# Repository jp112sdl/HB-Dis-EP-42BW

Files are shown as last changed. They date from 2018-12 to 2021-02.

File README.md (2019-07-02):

# HB-Dis-EP-42BW (jetzt auch mit Color-Display Unterstützung)

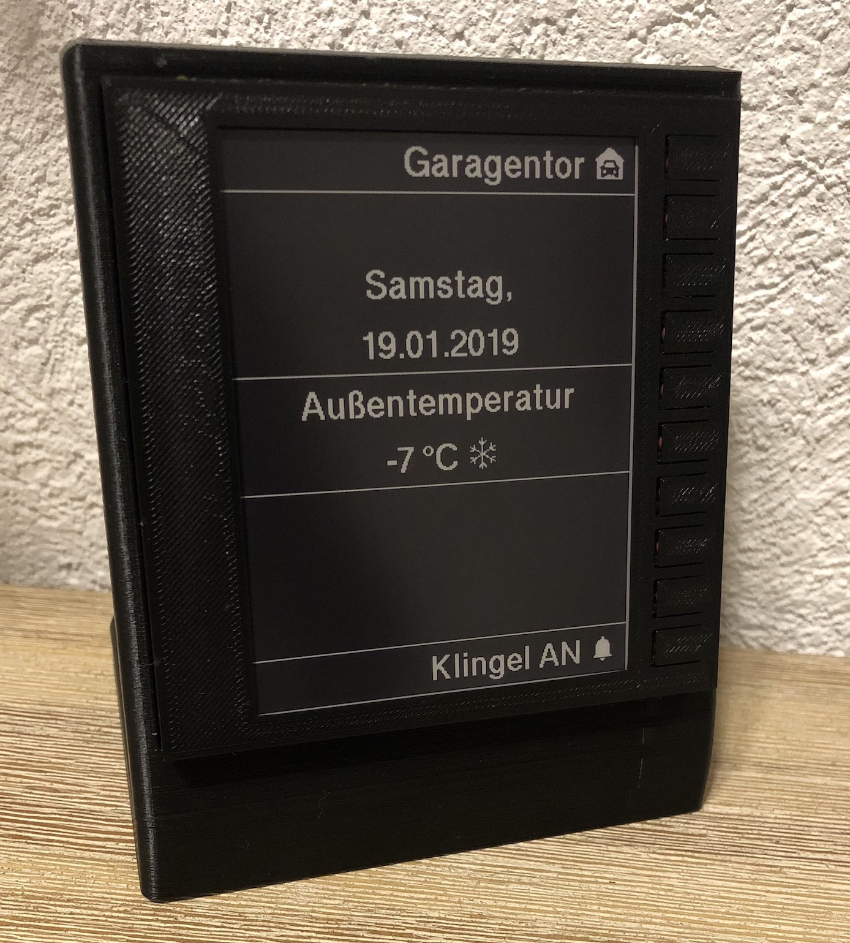
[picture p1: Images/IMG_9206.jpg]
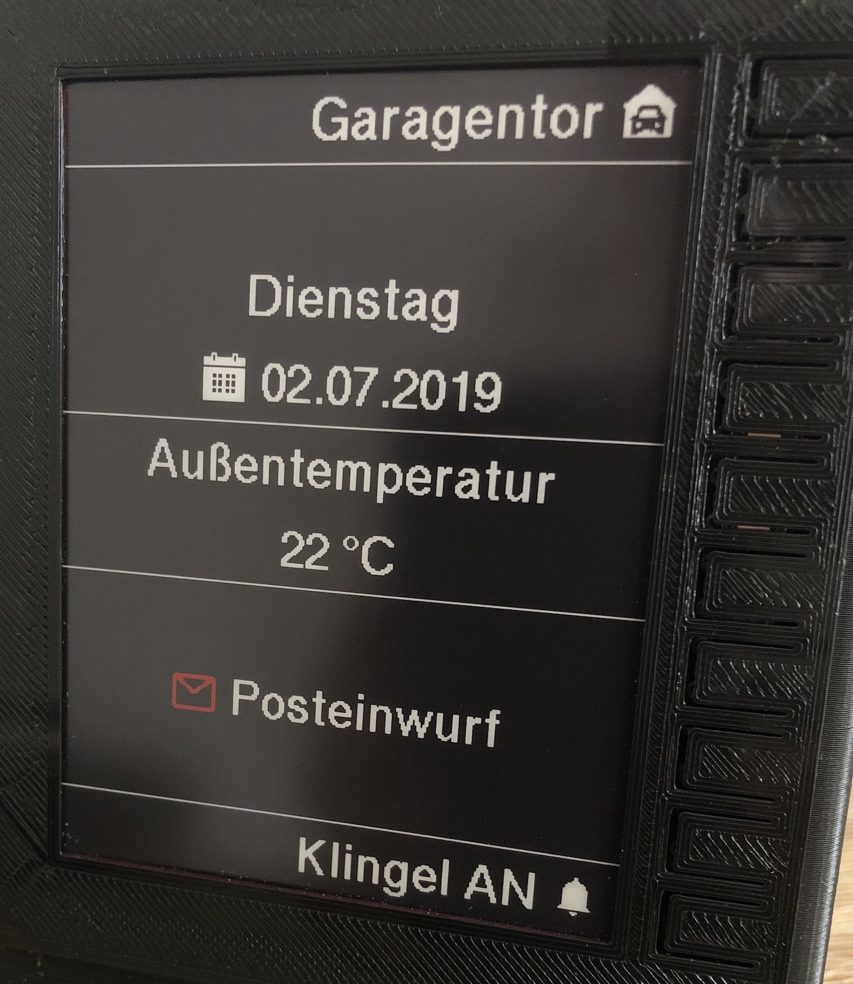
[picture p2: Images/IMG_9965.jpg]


## Infos
Thread im Homematic-Forum: https://homematic-forum.de/forum/viewtopic.php?f=76&t=48153

## Parts
- ATMega **1284P** (für den [Prototypen](https://github.com/jp112sdl/HB-Dis-EP-42BW/blob/master/Images/IMG_9180.jpg) habe ich die [HM-ES-PWMSw1-Pl_GosundSP1-Platine](https://raw.githubusercontent.com/stan23/HM-ES-PMSw1-Pl_GosundSP1/master/Bilder/Platine_V2_bestückt.jpg) missbraucht ^^)
- 11 Taster (10 Tasterkanäle + 1 Anlerntaster)
- 2 Widerstände 330 Ohm
- 2 LEDs oder 1 Dual-Color-LED
- 4.2" ePaper Display
  - [mit SPI Interface](https://www.exp-tech.de/new/8289/400x300-4.2-e-ink-display-module), passt dann jedoch nicht in die [Frontabdeckung](Images/ePaper-Front.stl) - da ist dann eigene Kreativität gefragt
  - [mit RAW Interface](https://www.exp-tech.de/displays/e-paper-e-ink/8885/waveshare-4.2-e-ink-raw-display-400x300), setzt jedoch noch ein SPI-Treiberboard voraus
    - [Universal e-Paper Raw Panel Driver HAT](https://www.exp-tech.de/displays/e-paper-e-ink/8525/universal-e-paper-raw-panel-driver-hat) oder
    - [CrystalFontz ePaper Adapter Board](https://www.crystalfontz.com/product/cfa10084-epaper-adapter-board)
- 2x 2fach AAA Batteriehalter (werden parallel betrieben; passte am besten ins [Gehäuse](https://github.com/jp112sdl/HB-Dis-EP-42BW/blob/master/Images/IMG_9181.jpg))    

## Arduino
- [MCUDude/MightyCore Board](https://github.com/MCUdude/MightyCore)-Unterstützung für den 1284P
  - Pinout: Standard
  - Clock: 8MHz external
  - BOD: Disabled
  - Compiler LTO: Disabled
  - Variant: 1284P
- Bibliotheken:  
  - [AskSinPP](https://github.com/pa-pa/AskSinPP) (master-Branch verwenden!)
  - [Low-Power](https://github.com/rocketscream/Low-Power)
  - [EnableInterrupt](https://github.com/GreyGnome/EnableInterrupt)
  - [GxEPD](https://github.com/ZinggJM/GxEPD) 
    - :arrow_right: um die Display-Aktualisierungsdauer zu verringern, lohnt es sich, in der `GxGDEW042T2.h` den Wert für [`GxGDEW042T2_PAGES`](https://github.com/ZinggJM/GxEPD/blob/master/src/GxGDEW042T2/GxGDEW042T2.h#L25) auf `3` zu reduzieren
  - [Adafruit-GFX](https://github.com/adafruit/Adafruit-GFX-Library)
  - [U8g2_for_Adafruit_GFX](https://github.com/olikraus/U8g2_for_Adafruit_GFX)

## Gehäuse
### Stand
https://www.thingiverse.com/thing:3331473

### Front
[Front](Images/ePaper-Front.stl)

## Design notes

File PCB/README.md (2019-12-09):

# HB-Dis-EP-42BW Platine     

# Work in Progress - in Bearbeitung...

# Hardware

### Bauteile

#### Reichelt

[Bestellliste](https://www.reichelt.de/my/1564026) (ohne die optionalen Bauteile)

Bauteil                  | Bestellnummer    | Anzahl | Kommentar
------------------------ | ---------------- | ------ | ---------
C1                       | X5R-G0603 10/6   |   1    | -
C2 .. C5, C7             | X7R-G0603 100N   |   5    | -
C6, C8                   | X7R-G0603 1,0/16 |   2    | -
D1                       | KBT L-115WEGW    |   1    | -
R1, R5                   | RND 0603 1 10K   |   2    | -
R2 .. R3                 | RND 0603 1 330   |   2    | -
R4                       | RND 0603 1 1,0M  |   1    | -
R6                       | RND 0603 1 4,7k  |   1    | optional: für Batteriespannungsmessung unter Last
R7                       | RND 155HP05 CI   |   1    | optional: für Batteriespannungsmessung unter Last
R8                       | RND 155HP05 AF   |   1    | optional: für Batteriespannungsmessung unter Last
Q1                       | IRLML 6344       |   1    | optional: für Batteriespannungsmessung unter Last
SW0                      | TASTER 3301      |   1    | optional: Konfigtaster *Achtung, diese Bauhöhe ist für die Montage kopfüber!*
SW1 .. SW10              | JTP-1130         |  10    | *Achtung, evtl. andere Bauhöhe!*
U1                       | ATMEGA 1284P-AU  |   1    | -
Y1                       | CSTCE 8,00       |   1    | -
Verbinder zum CC1101     | MPE 150-1-010    |   1    | -
Verbinder zum ePaper     | MPE 087-1-010    |   1    | -
Verbinder zur Batterie   | -                |   -    | optional, kann auch angelötet werden
Batteriefach             | HALTER 2XUM4-NLF |   -    | optional, für 2x AAA
Batteriefach             | HALTER 2XAAZ     |   -    | optional, für 2x AA

#### Farnell

Bauteil                  | Bestellnummer    | Anzahl | Kommentar
------------------------ | ---------------- | ------ | ---------
U3                       | [MCP111T-270E/TT](https://de.farnell.com/microchip/mcp111t-270e-tt/ic-supervisor-2-63v-low-sot-23b/dp/1851877)  |   1    | optional, Unterspannungserkennung

#### Sonstiges

Bauteil | Bezeichnung                  | Anzahl | Kommentar
------- | ---------------------------- | ------ | ---------
U2      | CC1101 Funkmodul 868 MHz     |   1    | z.B. [eBay](https://www.ebay.de/itm/272455136087)
Display | 4,2" ePaper mit SPI-Anschluss|   1    | z.B. [EXP-R63-045](https://www.exp-tech.de/new/8289/400x300-4.2-e-ink-display-module)

~8,3 cm Draht als Antenne

### Programmieradapter
- 1x ISP (z.B. [diesen hier](https://www.diamex.de/dxshop/USB-ISP-Programmer-fuer-Atmel-AVR-Rev2))

# Software

### Fuses und Lockbits

Fuse     | Wert | Kommentar
-------- | ---- | ---------
Extended | 0xFF |
High     | 0xD4 |
Low      | 0xFF |
Lockbits | 0xEF | optional

`C:\Program Files (x86)\Arduino\hardware\tools\avr\bin> .\avrdude -C ..\etc\avrdude.conf -p m1284p -P com7 -c stk500 -U lfuse:w:0xFF:m -U hfuse:w:0xD4:m -U efuse:w:0xFF:m`

### Firmware

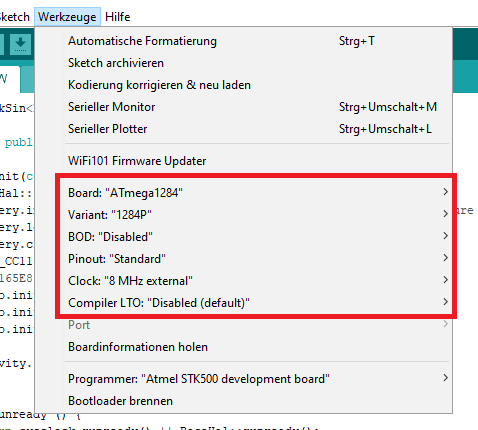
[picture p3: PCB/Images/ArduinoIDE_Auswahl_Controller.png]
Einstellungen IDE


# Bauanleitung

Zuerst den ATmega auflöten, die Markierung (kleiner Punkt) muss zur Beschriftung U1 zeigen.
Danach den Resonator, die Kondensatoren und Widerstände auflöten.

Mit einem Multimeter messen ob kein Kurzschluss zwischen VCC und GND besteht (mehrere 10 K Widerstand sind okay).

Den ISP Programmieradapter an den 6-poligen Anschluss auf der **Rückseite** anschließen.
Nun kann entweder der Sketch direkt geflasht werden ("Hochladen mit Programmer"), oder zuerst der [Bootloader](https://github.com/TomMajor/SmartHome/tree/master/Info/Bootloader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) und dann der eigentliche Sketch über den FTDI-Anschluss.

Pin am ISP-Kabel | Bedeutung
---------------- | ----------
1                | MISO
2                | VCC
3                | SCK
4                | MOSI
5                | Reset
6                | GND

Anschließend können das Funkmodul, die Taster und die LED eingelötet werden.

An den Antennenanschluss muss noch das 8,3 cm Drahtstück angelötet werden.

Mit einem FTDI USB-seriell-Adapter und einem Terminalprogramm kann man die Ausgabe beobachten. Es sollten schon *Ignore...*-Meldungen empfangen und angezeigt werden.

# ToDo

#### Abstände ePaper zu Platine
#### Höhe der Taster
#### Konfigtaster
Orientierung wie die anderen 10 Taster, oder über Kopf.
#### Ausrichtung LED
#### Abstandsbolzen
#### Befestigung im Gehäuse
#### Batterien 2x AA statt 2x 2x AAA

# Bilder



Dieses Werk ist lizenziert unter einer [Creative Commons Namensnennung - Nicht-kommerziell - Weitergabe unter gleichen Bedingungen 3.0 International Lizenz](http://creativecommons.org/licenses/by-nc-sa/3.0/).

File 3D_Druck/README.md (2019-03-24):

# HB-Dis-EP-42BW-3D-Modell

front.stl für diesen Display Version:
https://www.waveshare.com/4.2inch-e-Paper.htm

front-spi_pcb.stl für diesen Display Version:
https://www.waveshare.com/4.2inch-e-paper-module.htm

Standard Dicke 0,4 bei der Version 06 ist die Front 0,6mm Dick

Die Basis ist passend für beide Versionen und hat ein extra großes Batteriefach.

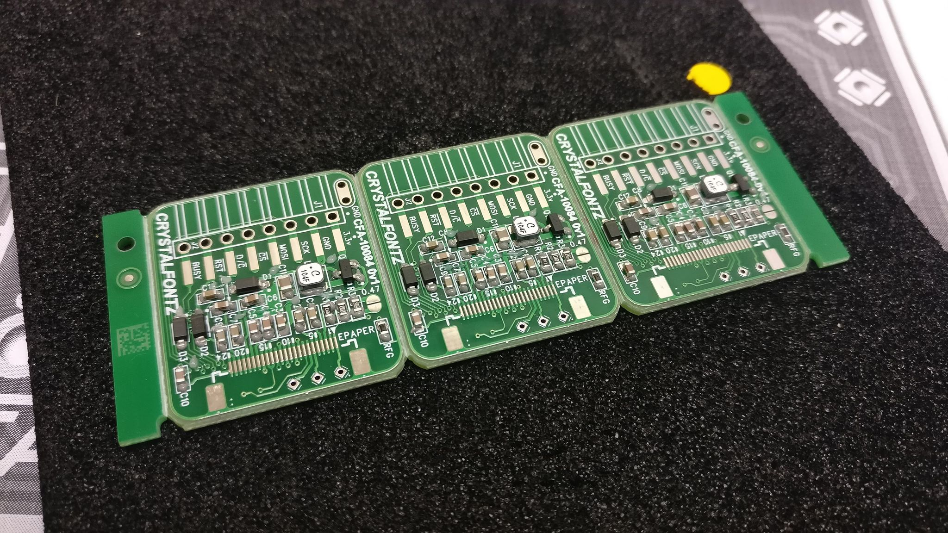
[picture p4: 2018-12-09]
Images/CF_Platine1.jpg

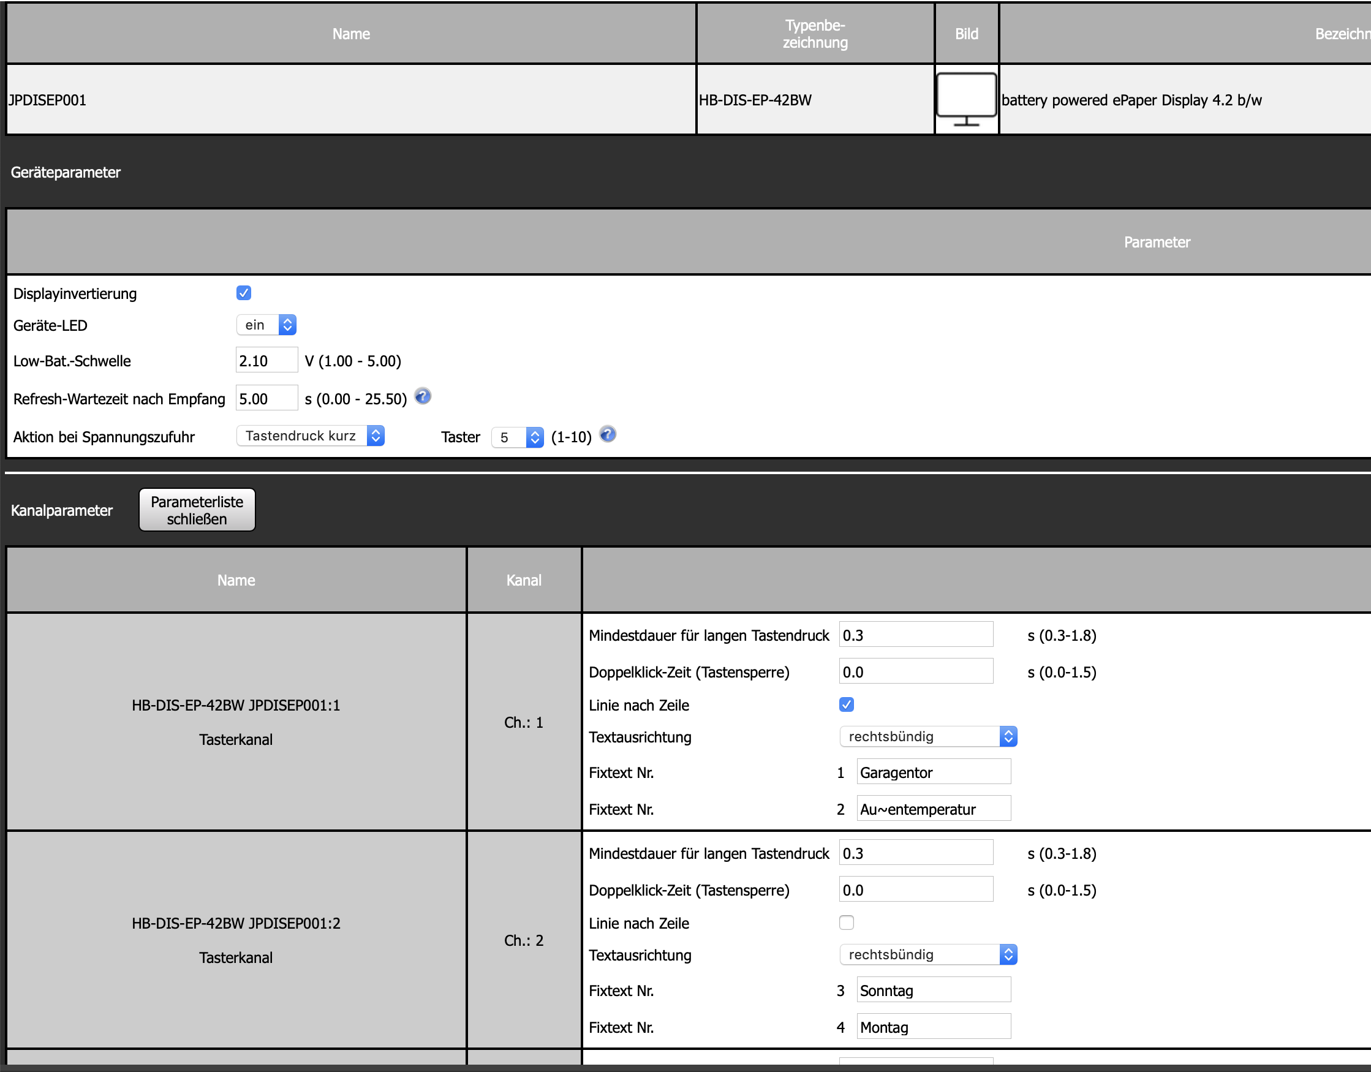
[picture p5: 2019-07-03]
Images/CCU_Einstellungen.png

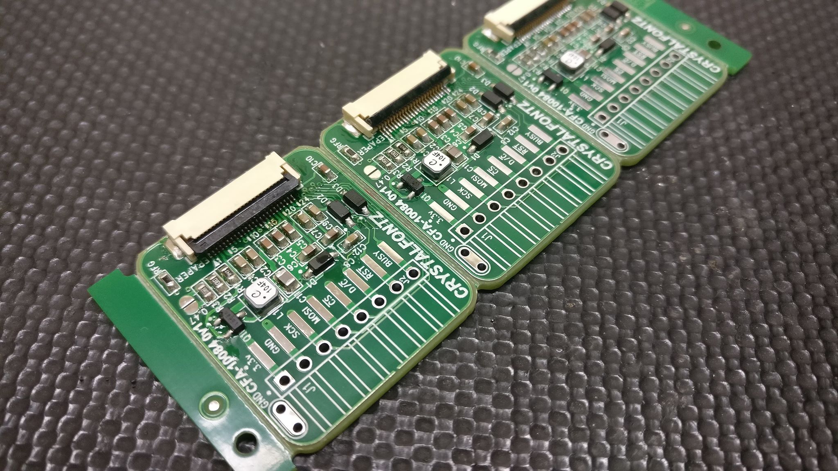
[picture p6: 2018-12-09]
Images/CF_Platine2.jpg

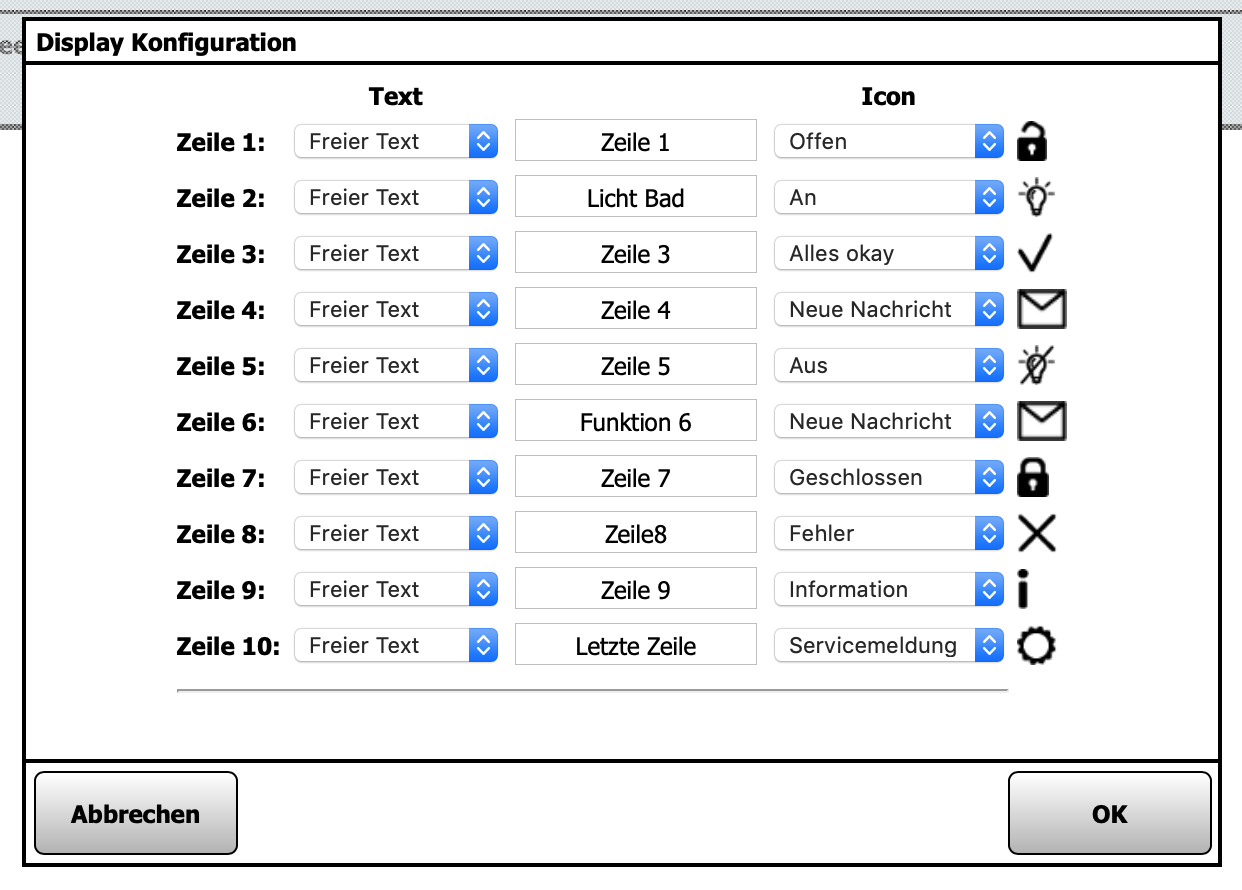
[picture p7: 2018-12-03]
Images/CCU_Programm_CH11.png

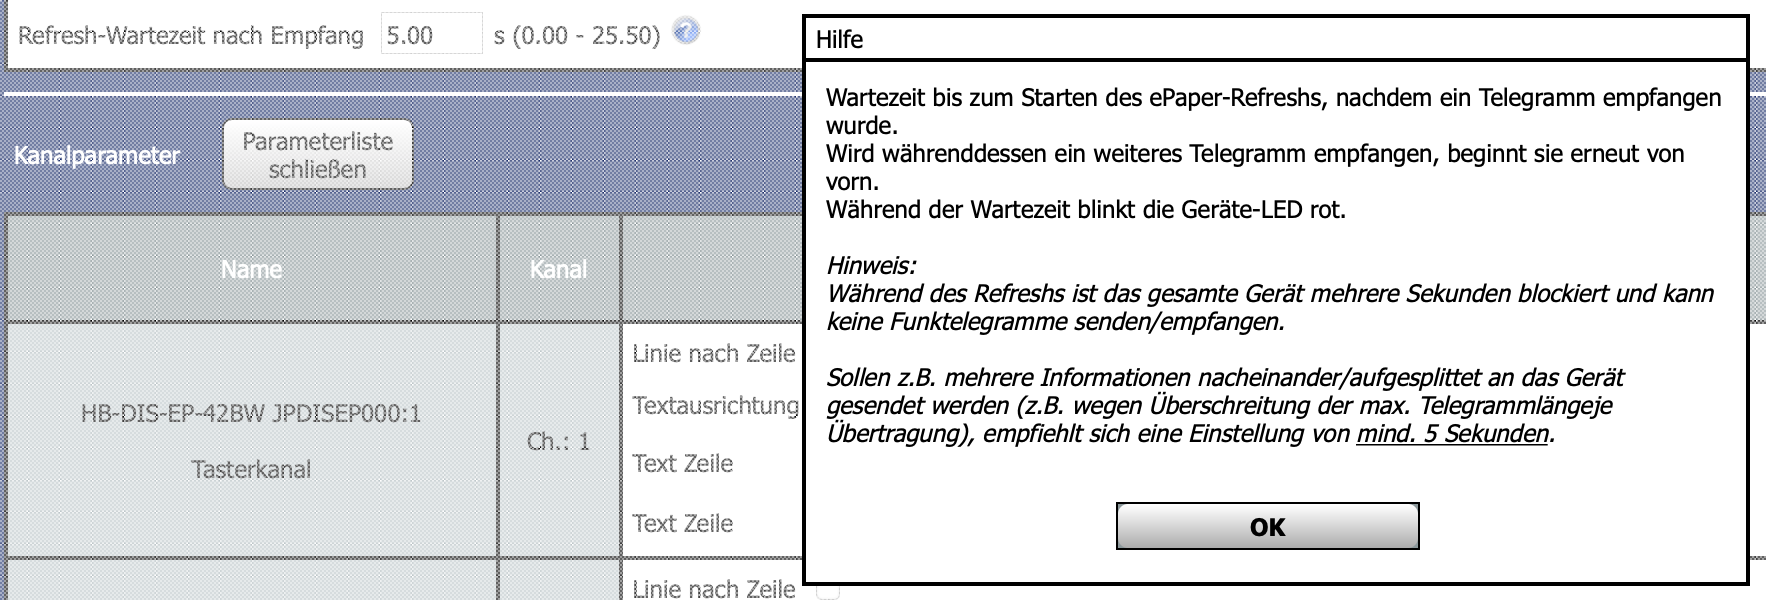
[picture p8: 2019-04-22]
Images/CCU_Einstellungen_Hilfe.png

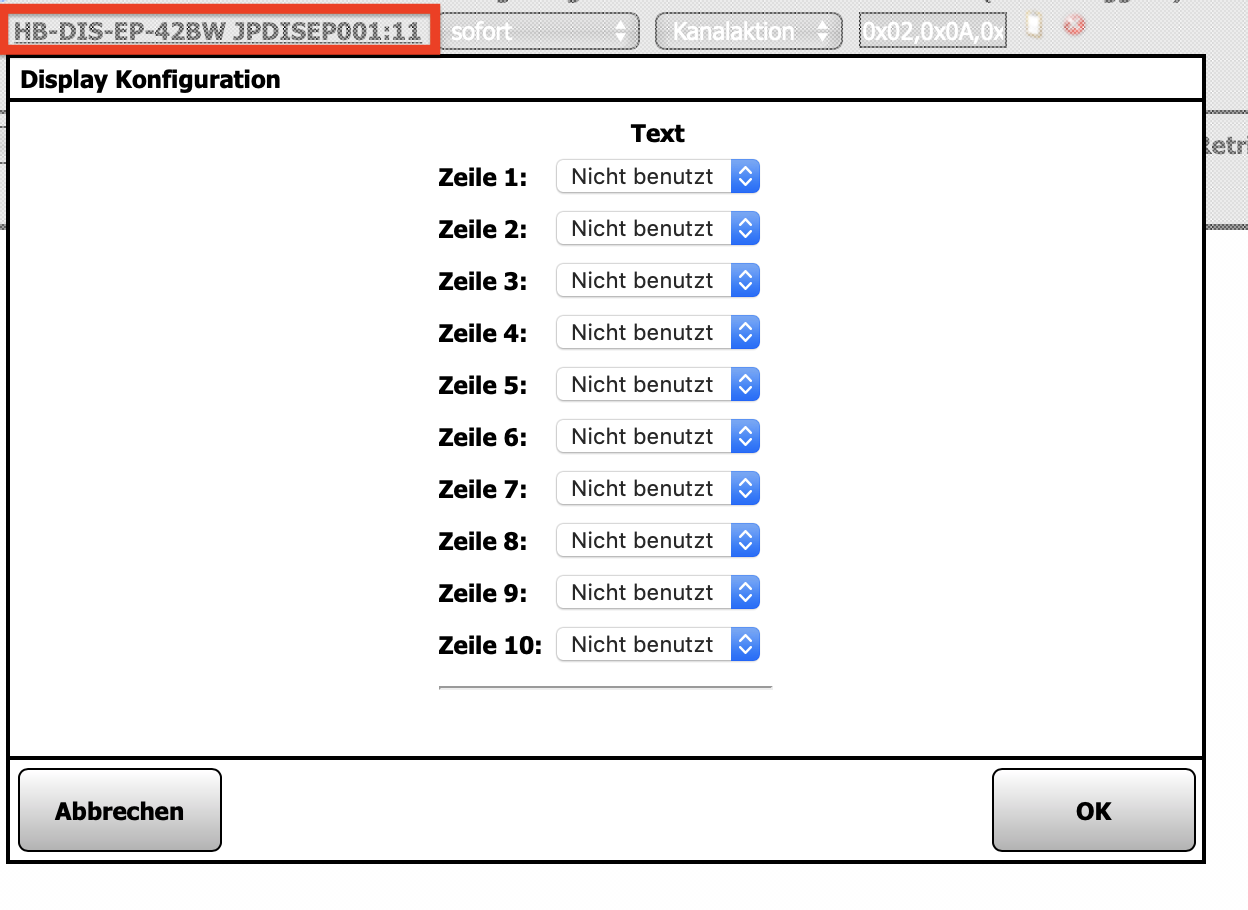
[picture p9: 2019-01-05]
Images/CCU_Programm.png

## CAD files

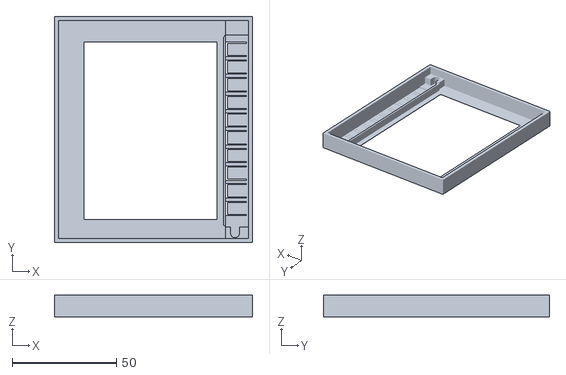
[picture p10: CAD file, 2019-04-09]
3D_Druck/front-spi.stl
95.0 x 108.6 x 10.4

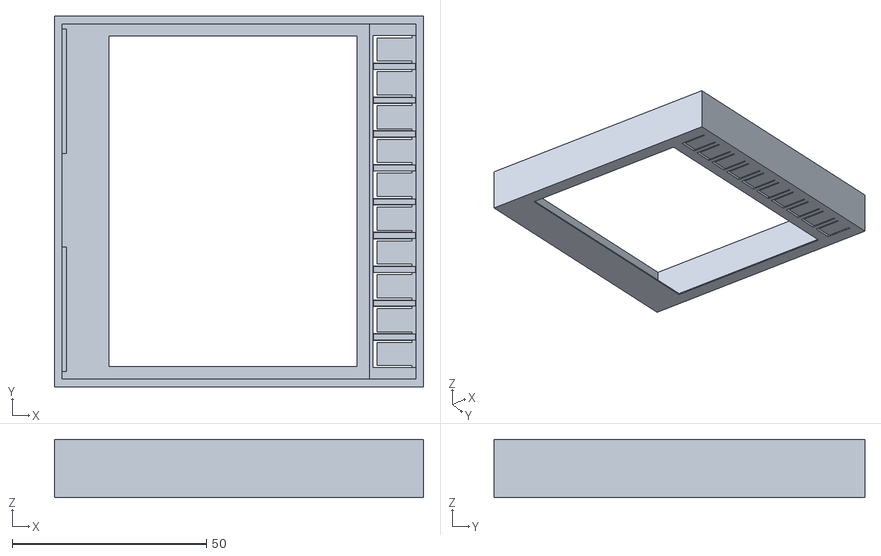
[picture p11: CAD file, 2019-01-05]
Images/ePaper-Front.stl
95.0 x 95.4 x 15.0

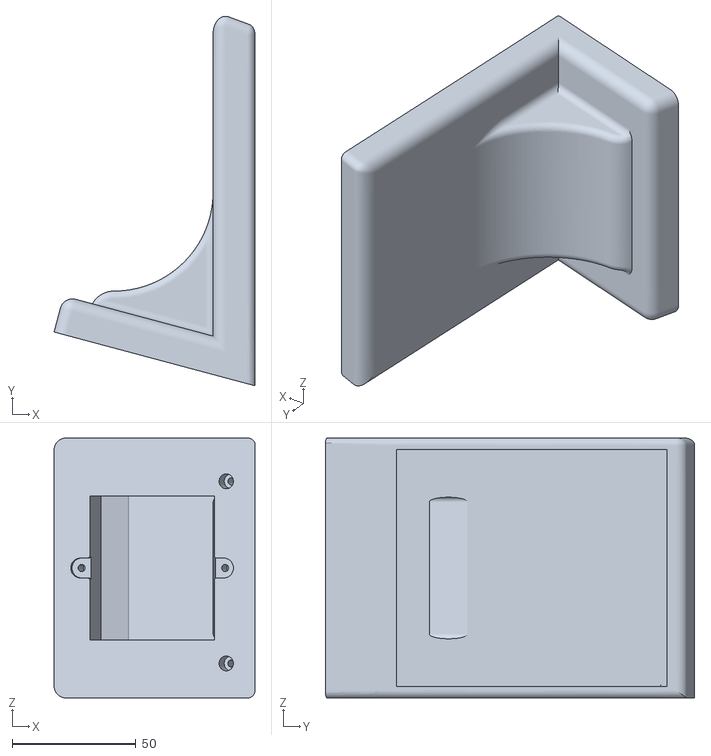
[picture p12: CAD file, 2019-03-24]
3D_Druck/basis.stl
81.2 x 149.2 x 105.0

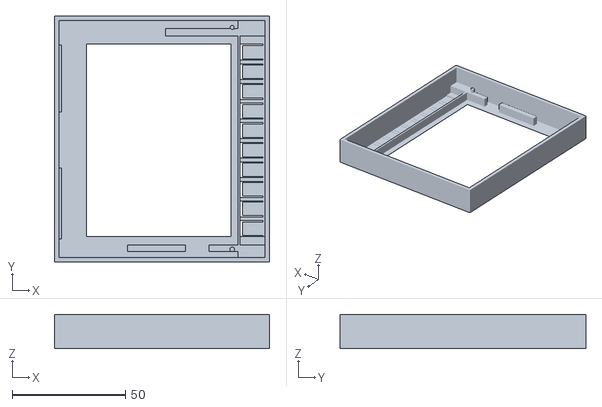
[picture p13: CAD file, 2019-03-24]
3D_Druck/front.stl
95.0 x 108.6 x 15.0

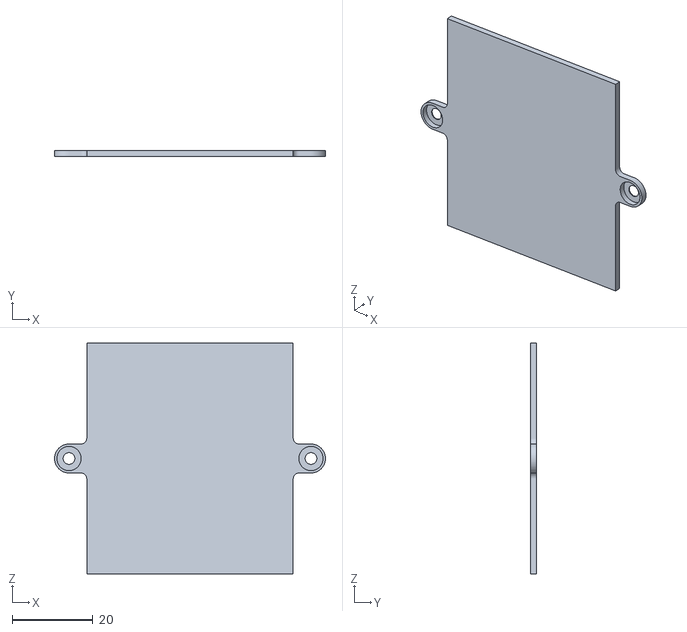
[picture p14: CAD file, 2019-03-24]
3D_Druck/Basis_Batterie_Deckel.stl
67.2 x 1.60 x 57.2

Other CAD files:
3D_Druck/front06.stl

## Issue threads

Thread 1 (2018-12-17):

add BI protection

stan23, 2018-12-17:
A protection against [Babbling Idiot](https://github.com/TomMajor/AskSinPP_Examples/tree/master/Info/Babbling%20Idiot%20Protection) shall be added.
If it is not populated, there shall be a way to bypass it.

stan23, 2019-01-13:
Two options to circumvent BIs are added to the PCB in https://github.com/jp112sdl/HB-Dis-EP-42BW/commit/53e460dccab44cdeac5f58302a134860578abbe9
- battery measurement under load
- external BOD (MCP111)

Both are optional to populate.

Closed 2019-01-13.

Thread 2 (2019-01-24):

Dreifarbiges Waveshare E-Paper Display

Alveran81, 2019-01-24:
Hallo,
ist es möglich auch das dreifarbige E-Paper Display einzubinden? Habe versehentlich das falsche bestellt. Es würde auch reichen wenn rot erstmal nicht verwendet wird.
Genau gesagt dieses:
https://www.waveshare.com/wiki/4.2inch_e-Paper_Module_(B)
https://eckstein-shop.de/Waveshare-42-inch-400x300-E-Ink-E-Paper-Display-Module-Three-color-Arduino

Welche Library muss dafür geladen werden? Hab schon ewig im Netz dazu gesucht, konnte aber nichts sinnvolles finden.

jp112sdl, 2019-01-24:
Moin,

ja das geht. Ich hab bei mir auch das 3farbige und nutze nur b/w. 😄

Libs brauchst du alle, die hier unten aufgeführt sind:
https://github.com/jp112sdl/HB-Dis-EP-42BW#arduino

Closed 2019-02-04.

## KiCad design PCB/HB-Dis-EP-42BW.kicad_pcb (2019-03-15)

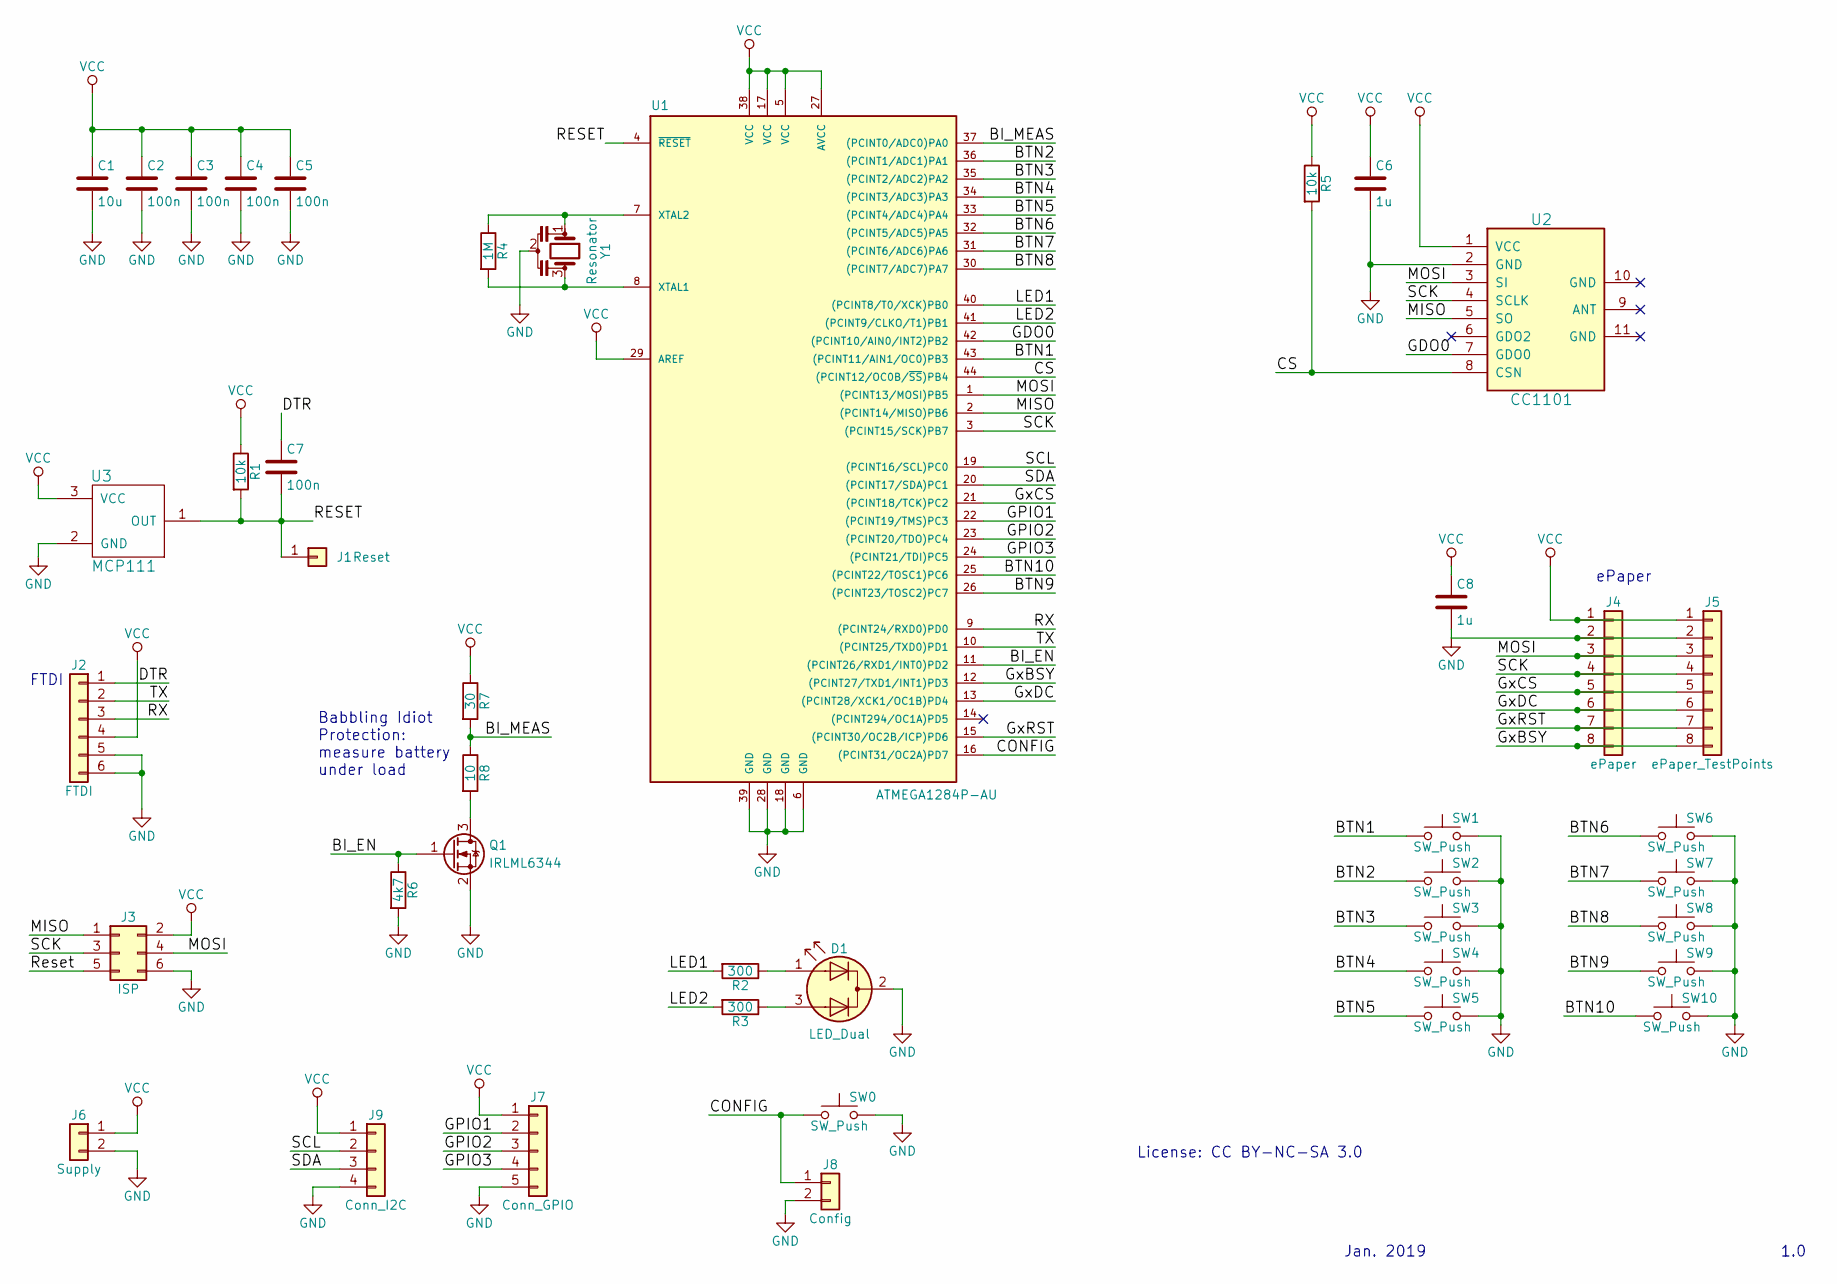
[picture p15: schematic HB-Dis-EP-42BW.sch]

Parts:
C1: 10u; C_0603_HandSoldering
C2, C3, C4, C5, C7: 100n; C_0603_HandSoldering
C6, C8: 1u; C_0603_HandSoldering
D1: LED_Dual; LED_D3.0mm-3
J1: Reset; Testpad
J2: FTDI; Pin_Header_Straight_1x06_Pitch2.54mm
J3: ISP; Pin_Header_Straight_2x03_Pitch2.54mm
J4: ePaper; Waveshare_4.2inch_Module
J5: ePaper_TestPoints; Pin_Header_Straight_1x08_Pitch2.54mm
J6: Supply; Pin_Header_Straight_1x02_Pitch2.54mm
J7: Conn_GPIO; Pin_Header_Straight_1x05_Pitch1.27mm
J8: Config; Pin_Header_Straight_1x02_Pitch2.54mm
J9: Conn_I2C; Pin_Header_Straight_1x04_Pitch1.27mm
Q1: IRLML6344; SOT-23
R1, R5: 10k; R_0603_HandSoldering
R2, R3: 300; R_0603_HandSoldering
R4: 1M; R_0603_HandSoldering
R6: 4k7; R_0603_HandSoldering
R7: 30; R_0603_HandSoldering
R8: 10; R_0603_HandSoldering
SW0, SW1, SW2, SW3, SW4, SW5, SW6, SW7, SW8, SW9, SW10: SW_Push; SW_PUSH_6mm
U1: ATMEGA1284P-AU; TQFP-44_10x10mm_Pitch0.8mm_HandSoldering
U2: CC1101; CC1101_Module
U3: MCP111; SOT-23
Y1: Resonator; Resonator_SMD_muRata_TPSKA-3pin_7.9x3.8mm_HandSoldering

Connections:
/BI_EN: Q1.1 (G), R6.1, U1.11 ((PCINT26/RXD1/INT0)PD2)
/BI_MEAS: R7.2, R8.1, U1.37 ((PCINT0/ADC0)PA0)
/BTN1: SW1.1, U1.43 ((PCINT11/AIN1/OC0)PB3)
/BTN2: SW2.1, U1.36 ((PCINT1/ADC1)PA1)
/BTN3: SW3.1, U1.35 ((PCINT2/ADC2)PA2)
/BTN4: SW4.1, U1.34 ((PCINT3/ADC3)PA3)
/BTN5: SW5.1, U1.33 ((PCINT4/ADC4)PA4)
/BTN6: SW6.1, U1.32 ((PCINT5/ADC5)PA5)
/BTN7: SW7.1, U1.31 ((PCINT6/ADC6)PA6)
/BTN8: SW8.1, U1.30 ((PCINT7/ADC7)PA7)
/BTN9: SW9.1, U1.26 ((PCINT23/TOSC2)PC7)
/BTN10: SW10.1, U1.25 ((PCINT22/TOSC1)PC6)
/CONFIG: J8.1, SW0.1, U1.16 ((PCINT31/OC2A)PD7)
/CS: R5.2, U1.44 ((PCINT12/OC0B/~SS~)PB4), U2.8 (CSN)
/DTR: C7.1, J2.1
/GDO0: U1.42 ((PCINT10/AIN0/INT2)PB2), U2.7 (GDO0)
/GPIO1: J7.2, U1.22 ((PCINT19/TMS)PC3)
/GPIO2: J7.3, U1.23 ((PCINT20/TDO)PC4)
/GPIO3: J7.4, U1.24 ((PCINT21/TDI)PC5)
/GxBSY: J4.8, J5.8, U1.12 ((PCINT27/TXD1/INT1)PD3)
/GxCS: J4.5, J5.5, U1.21 ((PCINT18/TCK)PC2)
/GxDC: J4.6, J5.6, U1.13 ((PCINT28/XCK1/OC1B)PD4)
/GxRST: J4.7, J5.7, U1.15 ((PCINT30/OC2B/ICP)PD6)
/LED1: R2.2, U1.40 ((PCINT8/T0/XCK)PB0)
/LED2: R3.2, U1.41 ((PCINT9/CLKO/T1)PB1)
/MISO: J3.1, U1.2 ((PCINT14/MISO)PB6), U2.5 (SO)
/MOSI: J3.4, J4.3, J5.3, U1.1 ((PCINT13/MOSI)PB5), U2.3 (SI)
/RESET: C7.2, J1.1, J3.5, R1.2, U1.4 (~RESET), U3.1 (OUT)
/RX: J2.3, U1.9 ((PCINT24/RXD0)PD0)
/SCK: J3.3, J4.4, J5.4, U1.3 ((PCINT15/SCK)PB7), U2.4 (SCLK)
/SCL: J9.2, U1.19 ((PCINT16/SCL)PC0)
/SDA: J9.3, U1.20 ((PCINT17/SDA)PC1)
/TX: J2.2, U1.10 ((PCINT25/TXD0)PD1)
GND: C1.2, C2.2, C3.2, C4.2, C5.2, C6.2, C8.2, D1.2 (K), J2.5, J2.6, J3.6, J4.2, J5.2, J6.2, J7.5, J8.2, J9.4, Q1.2 (S), R6.2, SW0.2, SW1.2, SW2.2, SW3.2, SW4.2, SW5.2, SW6.2, SW7.2, SW8.2, SW9.2, SW10.2, U1.6 (GND), U1.18 (GND), U1.28 (GND), U1.39 (GND), U2.2 (GND), U3.2 (GND), Y1.2
unnamed: D1.1 (A1), R2.1
unnamed: D1.3 (A2), R3.1
unnamed: Q1.3 (D), R8.2
unnamed: R4.1, U1.7 (XTAL2), Y1.1
unnamed: R4.2, U1.8 (XTAL1), Y1.3
VCC: C1.1, C2.1, C3.1, C4.1, C5.1, C6.1, C8.1, J2.4, J3.2, J4.1, J5.1, J6.1, J7.1, J9.1, R1.1, R5.1, R7.1, U1.5 (VCC), U1.17 (VCC), U1.27 (AVCC), U1.29 (AREF), U1.38 (VCC), U2.1 (VCC), U3.3 (VCC)

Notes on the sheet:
FTDI
1.0
License: CC BY-NC-SA 3.0
Jan. 2019
ePaper
Babbling Idiot Protection: measure battery under load

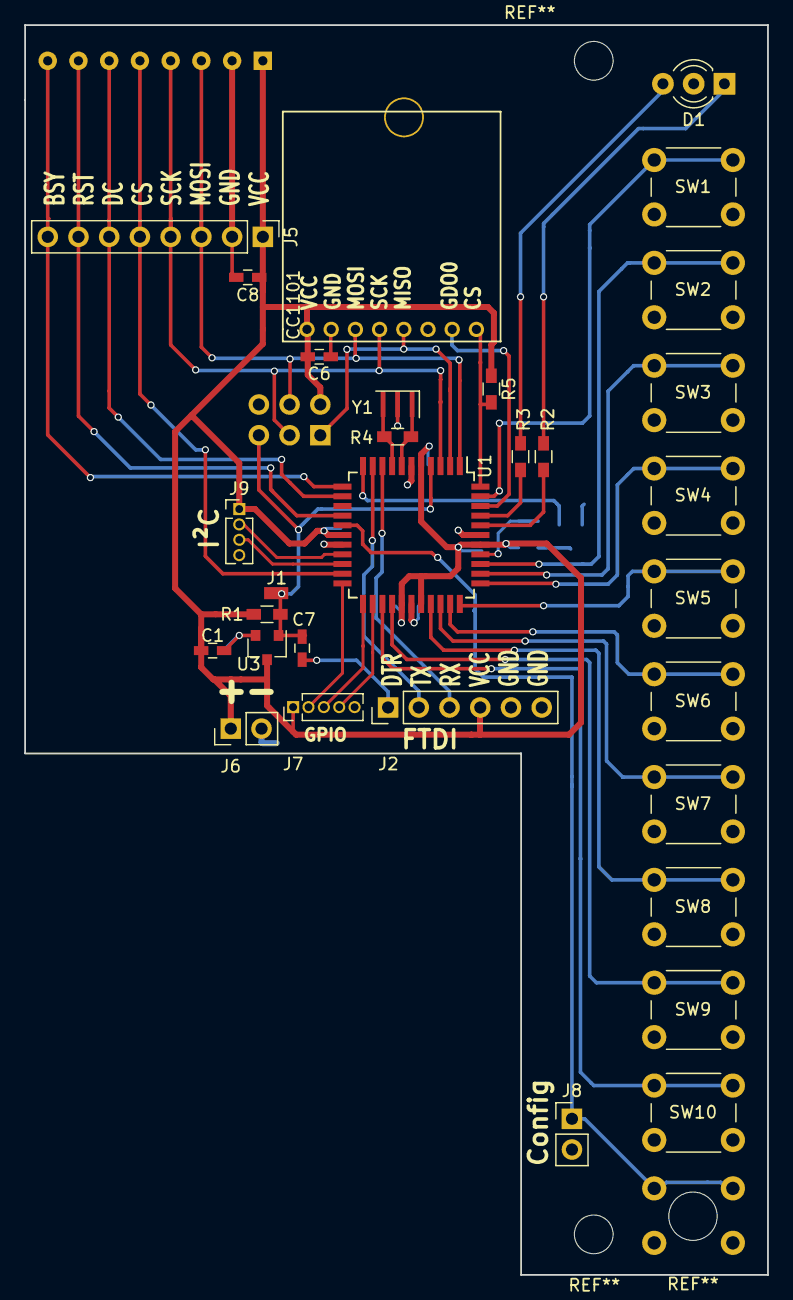
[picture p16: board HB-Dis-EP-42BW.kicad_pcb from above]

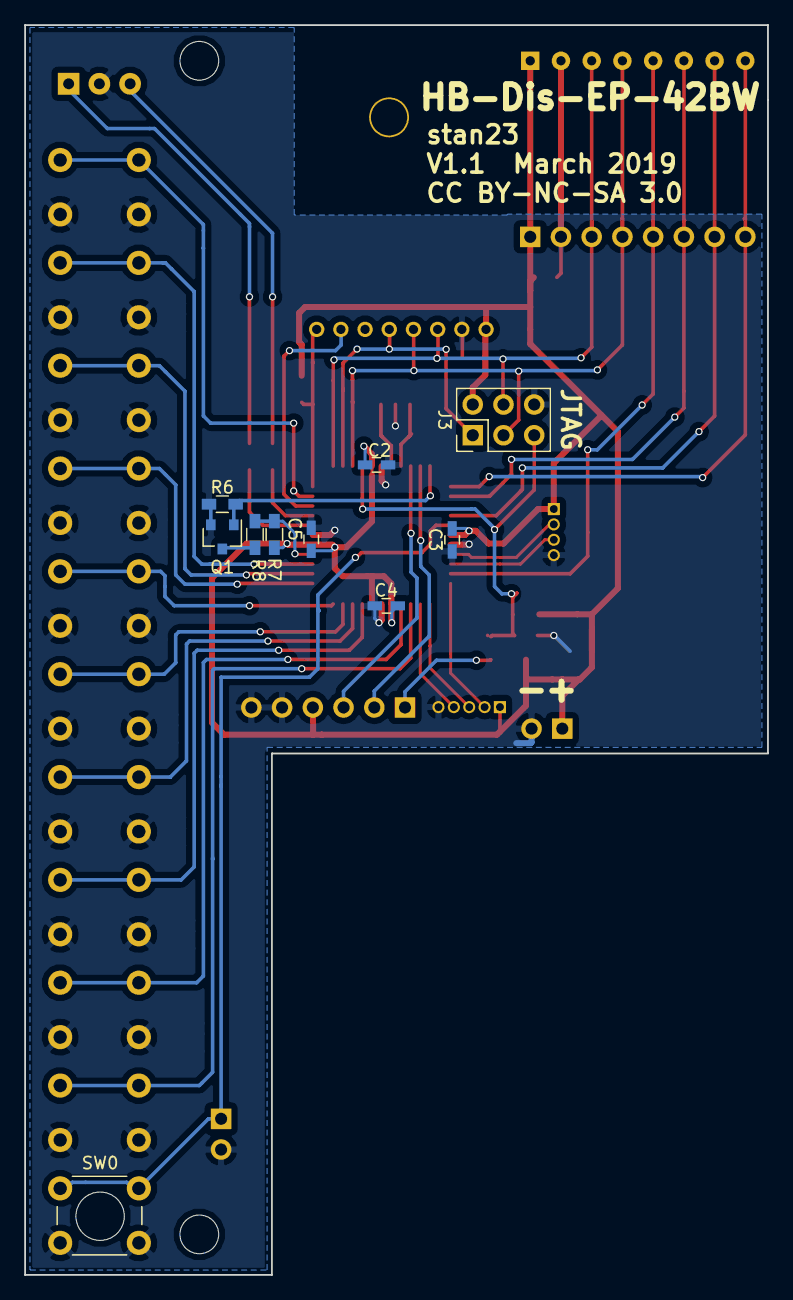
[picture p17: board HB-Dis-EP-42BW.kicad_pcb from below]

Board: 2 copper layers, 61.4 x 103.3 mm, 42 parts (10 on the bottom side), 40 nets.

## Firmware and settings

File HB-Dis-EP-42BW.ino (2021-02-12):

//- -----------------------------------------------------------------------------------------------------------------------
// AskSin++
// 2016-10-31 papa Creative Commons - http://creativecommons.org/licenses/by-nc-sa/3.0/de/
// 2018-12-01 jp112sdl Creative Commons - http://creativecommons.org/licenses/by-nc-sa/3.0/de/
//- -----------------------------------------------------------------------------------------------------------------------
// ci-test=yes board=1284pSTD aes=no

// use Arduino IDE Board Setting: STANDARD Layout

// define this to read the device id, serial and device type from bootloader section
// #define USE_OTA_BOOTLOADER
// #define USE_HW_SERIAL
// #define NDEBUG
// #define NDISPLAY
// #define USE_COLOR

#define BATTERY_MODE

#ifdef BATTERY_MODE
#define USE_WOR
#endif

//////////////////// DISPLAY DEFINITIONS /////////////////////////////////////
#include <GxEPD.h>
#ifdef USE_COLOR
#include <GxGDEW042Z15/GxGDEW042Z15.h>      // 4.2" color
#else
#include <GxGDEW042T2/GxGDEW042T2.h>        // 4.2" b/w
#endif

#include <GxIO/GxIO_SPI/GxIO_SPI.h>
#include <GxIO/GxIO.h>
#include "U8G2_FONTS_GFX.h"

#define GxRST_PIN  14   // PD6
#define GxBUSY_PIN 11   // PD3
#define GxDC_PIN   12   // PD4
#define GxCS_PIN   18   // PC2

GxIO_Class io(SPI, GxCS_PIN, GxDC_PIN, GxRST_PIN);
GxEPD_Class display(io, GxRST_PIN, GxBUSY_PIN);

U8G2_FONTS_GFX u8g2Fonts(display);
//////////////////////////////////////////////////////////////////////////////

#define EI_NOTEXTERNAL
#include <EnableInterrupt.h>

#include <AskSinPP.h>
#include <LowPower.h>

#include <Register.h>
#include <Remote.h>
#include <MultiChannelDevice.h>

// make compatible with v5.0.0
#ifndef ASKSIN_PLUS_PLUS_VERSION_STR
  #define ASKSIN_PLUS_PLUS_VERSION_STR ASKSIN_PLUS_PLUS_VERSION
#endif

#define CC1101_CS_PIN       4   // PB4
#define CC1101_GDO0_PIN     2   // PB2
#define CC1101_SCK_PIN      7   // PB7
#define CC1101_MOSI_PIN     5   // PB5
#define CC1101_MISO_PIN     6   // PB6
#define CONFIG_BUTTON_PIN  15   // PD7
#define LED_PIN_1           0   // PB0
#define LED_PIN_2           1   // PB1
#define BTN1_PIN            3   // PB3
#define BTN2_PIN           A1   // PA1
#define BTN3_PIN           A2   // PA2
#define BTN4_PIN           A3   // PA3
#define BTN5_PIN           A4   // PA4
#define BTN6_PIN           A5   // PA5
#define BTN7_PIN           A6   // PA6
#define BTN8_PIN           A7   // PA7
#define BTN9_PIN           23   // PC7
#define BTN10_PIN          22   // PC6

#define TEXT_LENGTH        16
#define DISPLAY_LINES      10

#define DISPLAY_ROTATE     3 // 0 = 0° , 1 = 90°, 2 = 180°, 3 = 270°

#define PEERS_PER_CHANNEL   8
#define NUM_CHANNELS        11
#define DEF_LOWBAT_VOLTAGE  24
#define DEF_CRITBAT_VOLTAGE 22

#define MSG_START_KEY     0x02
#define MSG_TEXT_KEY      0x12
#define MSG_ICON_KEY      0x13
#define MSG_COLOR_OFFSET  0x04
#define MSG_CLR_LINE_KEY  0xFE
#define MSG_MIN_LENGTH    13
#define MSG_BUFFER_LENGTH 224
#define MSG_OUTOFHOUSE    0xFD

#include "Icons.h"

// all library classes are placed in the namespace 'as'
using namespace as;

const struct DeviceInfo PROGMEM devinfo = {
  {0xf3, 0x43, 0x00},          // Device ID
  "JPDISEP000",                // Device Serial
#ifdef BATTERY_MODE
  {0xf3, 0x43},                // Device Model
#else
  {0xf3, 0x53},                // Device Model
#endif
  0x11,                        // Firmware Version
  as::DeviceType::Remote,      // Device Type
  {0x01, 0x01}                 // Info Bytes
};

enum Alignments {AlignRight = 0, AlignCenterIconRight = 1, AlignCenterIconLeft = 3, AlignLeft = 2};

typedef struct {
  uint8_t Alignment = AlignRight;
  uint8_t Icon      = 0xff;
  bool IconColored  = false;
  String Text       = "";
  bool TextColored  = false;
  bool showLine     = false;
} DisplayLine;
DisplayLine DisplayLines[DISPLAY_LINES];

String List1Texts[DISPLAY_LINES * 2];

bool runSetup          = true;

/**
   Configure the used hardware
*/
typedef AvrSPI<CC1101_CS_PIN, CC1101_MOSI_PIN, CC1101_MISO_PIN, CC1101_SCK_PIN> SPIType;
typedef Radio<SPIType, CC1101_GDO0_PIN> RadioType;
typedef StatusLed<LED_PIN_1> LedType;

#ifdef BATTERY_MODE
typedef AskSin<LedType, BatterySensor, RadioType> BaseHal;
#else
typedef AskSin<LedType, NoBattery, RadioType> BaseHal;
#endif

class Hal: public BaseHal {
  public:
    void init(const HMID& id) {
      BaseHal::init(id);
#ifdef BATTERY_MODE
      battery.init(seconds2ticks(60UL * 60 * 21), sysclock); //battery measure once an day
      battery.low(DEF_LOWBAT_VOLTAGE);
      battery.critical(DEF_CRITBAT_VOLTAGE);
      activity.stayAwake(seconds2ticks(15));
#endif
    }

    bool runready () {
      return sysclock.runready() || BaseHal::runready();
    }
} hal;


void initDisplay();
void updateDisplay();
void emptyBatteryDisplay();
void outOfHouseDisplay();
class ePaperType : public Alarm {
  class ePaperWorkingLedType : public StatusLed<LED_PIN_2>  {
  private:
    bool enabled;
  public:
    ePaperWorkingLedType () : enabled(true) {}
    virtual ~ePaperWorkingLedType () {}
    void Enabled(bool e) {
      enabled = e;
    }
    bool Enabled() {
      return enabled;
    }
  } workingLed;
private:
  bool                 mUpdateDisplay;
  bool                 shInitDisplay;
  bool                 shOutOfHouseDisplay;
  bool                 inverted;
  bool                 waiting;
  uint16_t             clFG;
  uint16_t             clBG;
public:
  ePaperType () :  Alarm(0), mUpdateDisplay(false), shInitDisplay(false), shOutOfHouseDisplay(false), inverted(false), waiting(false), clFG(GxEPD_BLACK), clBG(GxEPD_WHITE)  {}
  virtual ~ePaperType () {}

  uint16_t ForegroundColor() {
    return clFG;
  }

  void ForegroundColor(uint16_t c) {
    clFG = c;
  }

  uint16_t BackgroundColor() {
    return clBG;
  }

  void BackgroundColor(uint16_t c) {
    clBG = c;
  }

  bool Inverted() {
    return inverted;
  }

  void Inverted(bool i) {
    inverted = i;
  }

  bool showInitDisplay() {
    return shInitDisplay;
  }

  void showInitDisplay(bool s) {
    shInitDisplay = s;
  }

  bool showOutOfHouseDisplay() {
    return shOutOfHouseDisplay;
  }

  void showOutOfHouseDisplay(bool s) {
    shOutOfHouseDisplay = s;
  }

  bool mustUpdateDisplay() {
    return mUpdateDisplay;
  }

  void mustUpdateDisplay(bool m) {
    if (m == true && workingLed.Enabled() == true) workingLed.set(LedStates::pairing);
    mUpdateDisplay = m;
  }

  void init() {
    u8g2Fonts.begin(display);
    display.setRotation(DISPLAY_ROTATE);
    u8g2Fonts.setFontMode(1);
    u8g2Fonts.setFontDirection(0);
    workingLed.init();
  }

  void setWorkingLedEnabled(bool en) {
    workingLed.Enabled(en);
  }

  void setDisplayColors() {
    u8g2Fonts.setForegroundColor(ForegroundColor());
    u8g2Fonts.setBackgroundColor(BackgroundColor());
  }

  void isWaiting(bool w) {
    waiting = w;
    DPRINT("wait:"); DDECLN(waiting);
  }

  bool isWaiting() {
    return waiting;
  }

  void setRefreshAlarm (uint32_t t) {
    isWaiting(true);
    sysclock.cancel(*this);
    Alarm::set(millis2ticks(t));
    sysclock.add(*this);
  }
  virtual void trigger (__attribute__((unused)) AlarmClock& clock) {
    isWaiting(false);
    if (this->mustUpdateDisplay()) {
      this->mustUpdateDisplay(false);
  #ifndef NDISPLAY
      if (workingLed.Enabled() == true) {
        workingLed.set(LedStates::nothing);
        workingLed.ledOn();
      }
      setDisplayColors();
      if (this->showInitDisplay() == true) {
        this->showInitDisplay(false);
        display.drawPaged(initDisplay);
      } else if (this->showOutOfHouseDisplay() == true ) {
          display.drawPaged(outOfHouseDisplay);
          this->showOutOfHouseDisplay(false);
        } else {
          display.drawPaged(updateDisplay);
        }

      workingLed.ledOff();
  #else
      DPRINTLN("UPDATEDISPLAY!");
  #endif
    }
  }
} ePaper;

DEFREGISTER(Reg0, MASTERID_REGS, DREG_TRANSMITTRYMAX, DREG_LEDMODE, DREG_LOWBATLIMIT, 0x06, 0x07, 0x34, 0x35)
class DispList0 : public RegList0<Reg0> {
  public:
    DispList0(uint16_t addr) : RegList0<Reg0>(addr) {}

    bool displayInvertingHb(bool v) const { return this->writeRegister(0x06, 0x01,0,v); }
    bool displayInvertingHb() const { return this->readRegister(0x06, 0x01,0,false); }

    uint8_t displayRefreshWaitTime () const { return this->readRegister(0x07,0); }
    bool displayRefreshWaitTime (uint8_t value) const { return this->writeRegister(0x07,value); }

    uint8_t powerUpMode () const { return this->readRegister(0x34,0x03,0); }
    bool powerUpMode (uint8_t value) const { return this->writeRegister(0x34,0x03,0,value); }

    uint8_t powerUpKey () const { return this->readRegister(0x34,0x0f,2); }
    bool powerUpKey (uint8_t value) const { return this->writeRegister(0x34,0x0f,2,value); }

    uint8_t critBatLimit () const { return this->readRegister(0x35,0); }
    bool critBatLimit (uint8_t value) const { return this->writeRegister(0x35,value); }

    void defaults () {
      clear();
      displayInvertingHb(false);
      ledMode(1);
      transmitDevTryMax(2);
      displayRefreshWaitTime(50);
      powerUpMode(0);
      powerUpKey(0);
#ifdef BATTERY_MODE
      lowBatLimit(DEF_LOWBAT_VOLTAGE);
      critBatLimit(DEF_CRITBAT_VOLTAGE);
#endif
    }
};

DEFREGISTER(DispReg1)
class DispList1 : public RegList1<DispReg1> {
public:
  DispList1 (uint16_t addr) : RegList1<DispReg1>(addr) {}
  void defaults () {
    clear();
  }
};

DEFREGISTER(RemReg1, CREG_AES_ACTIVE, CREG_LONGPRESSTIME ,CREG_DOUBLEPRESSTIME, 0x36, 0x37, 0x38, 0x39, 0x3a, 0x3b, 0x3c, 0x3d, 0x3e, 0x3f, 0x40, 0x41, 0x42, 0x43, 0x44, 0x45, 0x46, 0x47, 0x48, 0x49, 0x4a, 0x4b, 0x4c, 0x4d, 0x4e, 0x4f, 0x50, 0x51, 0x52, 0x53, 0x54, 0x55, 0x90, 0x91)
class RemList1 : public RegList1<RemReg1> {
  public:
    RemList1 (uint16_t addr) : RegList1<RemReg1>(addr) {}

    bool showLine (uint8_t value) const {
      return this->writeRegister(0x90, 0x01, 0, value & 0xff);
    }
    bool showLine () const {
      return this->readRegister(0x90, 0x01, 0, false);
    }

    bool Alignment (uint8_t value) const {
      return this->writeRegister(0x91, value & 0xff);
    }
    uint8_t Alignment () const {
      return this->readRegister(0x91, 0);
    }

    bool TEXT1 (uint8_t value[TEXT_LENGTH]) const {
      for (int i = 0; i < TEXT_LENGTH; i++) {
        this->writeRegister(0x36 + i, value[i] & 0xff);
      }
      return true;
    }
    String TEXT1 () const {
      String a = "";
      for (int i = 0; i < TEXT_LENGTH; i++) {
        byte b = this->readRegister(0x36 + i, 0x20);
        if (b == 0x00) b = 0x20;
        a += char(b);
      }
      return a;
    }

    bool TEXT2 (uint8_t value[TEXT_LENGTH]) const {
      for (int i = 0; i < TEXT_LENGTH; i++) {
        this->writeRegister(0x46 + i, value[i] & 0xff);
      }
      return true;
    }
    String TEXT2 () const {
      String a = "";
      for (int i = 0; i < TEXT_LENGTH; i++) {
        byte b = this->readRegister(0x46 + i, 0x20);
        if (b == 0x00) b = 0x20;
        a += char(b);
      }
      return a;
    }

    void defaults () {
      clear();
      //aesActive(false);
      longPressTime(1);
      doublePressTime(0);
      uint8_t initValues[TEXT_LENGTH];
      memset(initValues, 0x00, TEXT_LENGTH);
      TEXT1(initValues);
      TEXT2(initValues);
      showLine(false);
      Alignment(AlignRight);
    }
};

class RemChannel : public RemoteChannel<Hal,PEERS_PER_CHANNEL,DispList0, RemList1>  {
public:
  RemChannel () : RemoteChannel() {}
    virtual ~RemChannel () {}
    void configChanged() {
      uint16_t _longpressTime = 300 + (this->getList1().longPressTime() * 100);
      setLongPressTime(millis2ticks(_longpressTime));

      List1Texts[(number() - 1)  * 2] = this->getList1().TEXT1();
      List1Texts[((number() - 1) * 2) + 1] = this->getList1().TEXT2();

      bool somethingChanged = (
                                DisplayLines[(number() - 1)].showLine != this->getList1().showLine() ||
                                DisplayLines[(number() - 1)].Alignment != this->getList1().Alignment()
                              );

      DisplayLines[(number() - 1)].showLine = this->getList1().showLine();
      DisplayLines[(number() - 1)].Alignment = this->getList1().Alignment();
      DPRINT(number() < 10 ? "0":"");DDEC(number()); DPRINT(F(" - TEXT1 = ")); DPRINT(this->getList1().TEXT1());DPRINT(F(" - TEXT2 = ")); DPRINT(this->getList1().TEXT2());DPRINT(F(" - Line  = ")); DDEC(this->getList1().showLine());DPRINT(F(" - Align = ")); DDECLN(this->getList1().Alignment());

      if (!runSetup && somethingChanged) ePaper.mustUpdateDisplay(true);
    }

    uint8_t flags () const {
      return hal.battery.low() ? 0x80 : 0x00;
    }
};
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
void loop() {
  bool worked = hal.runready();
  bool poll = sdev.pollRadio();
  if ( worked == false && poll == false ) {
#ifdef BATTERY_MODE
    if (hal.battery.critical()) {
      display.drawPaged(emptyBatteryDisplay);
      hal.activity.sleepForever(hal);
    }
    if (ePaper.isWaiting()) {
      hal.activity.savePower<Idle<>>(hal);
    } else {
      hal.activity.savePower<Sleep<>>(hal);
    }
#else
    hal.activity.savePower<Idle<>>(hal);
#endif
  }
}

uint16_t centerPosition(const char * text) {
  return (display.width() / 2) - (u8g2Fonts.getUTF8Width(text) / 2);
}

void PrintTextWithPosition(String text, int y)
{
  while (text.length()) {
    int pos1 = text.lastIndexOf("@p");
    int pos2 = text.lastIndexOf("@f");
    int pos = max(pos1, pos2);
    if (pos >= 0) {
      String tPos = text.substring(pos+2, pos+4); // Position als String
      String tText = text.substring(pos+4);  // Ausgabetext
      text.remove(pos);
      if (tText.length()) {
        uint16_t iPos = tPos.toInt();  // Position als int
        //Serial.print(iPos); Serial.print(" ");
        //Serial.print(tText); Serial.println(" ");
        uint16_t left = iPos * display.width() / 100u;
        u8g2Fonts.setCursor(left, y);
#ifdef USE_COLOR
        if (pos2 > pos1) {
          u8g2Fonts.setForegroundColor(GxEPD_RED);
        } else {
          u8g2Fonts.setForegroundColor(ePaper.ForegroundColor());
        }
#endif
        u8g2Fonts.print(tText);
      }
    } else {
      break;
    }
  }
#ifdef USE_COLOR
  ePaper.setDisplayColors();    // restore default colors for possible next line in loop updateDisplay()
#endif
}

void updateDisplay() {
  display.fillScreen(ePaper.BackgroundColor());
  u8g2Fonts.setFont(u8g2_font_helvB18_tf);

  for (uint16_t i = 0; i < 10; i++) {
    if (DisplayLines[i].showLine && i < 10) display.drawLine(0, ((i + 1) * 40), display.width(), ((i + 1) * 40), ePaper.ForegroundColor());
    //DisplayLines[i].Text.trim();
    String viewText = DisplayLines[i].Text;
    viewText.replace("{", "ä");
    viewText.replace("|", "ö");
    viewText.replace("}", "ü");
    viewText.replace("[", "Ä");
    viewText.replace("#", "Ö");
    viewText.replace("$", "Ü");
    viewText.replace("~", "ß");
    viewText.replace("'", "=");

    uint8_t icon_number = DisplayLines[i].Icon;
    uint16_t icon_top = (24 - ( Icons[icon_number].height / 2)) + (i * 40) - 4;

    uint16_t leftTextPos = 0xffff;
    uint16_t fontWidth = u8g2Fonts.getUTF8Width(viewText.c_str());

    bool icon_colored = DisplayLines[i].IconColored;

    uint16_t y = i * 40 + 30;

    switch (DisplayLines[i].Alignment) {
      case AlignLeft:
        // TomMajor Erweiterung x-Textposition
        if (viewText.startsWith("@p") || viewText.startsWith("@f")) {
            PrintTextWithPosition(viewText, y);
            continue;
        }
        leftTextPos = 40;
        if (icon_number != 255) display.drawBitmap(Icons[icon_number].Icon, (( 24 - Icons[icon_number].width ) / 2) + 8, icon_top, Icons[icon_number].width, Icons[icon_number].height, icon_colored ? GxEPD_RED : ePaper.ForegroundColor(), icon_colored ? GxEPD::bm_normal | GxEPD::bm_transparent | GxEPD::bm_invert : GxEPD::bm_default);
        break;
      case AlignCenterIconRight:
        leftTextPos = (display.width() / 2) - (fontWidth / 2);
        if (icon_number != 255) {
          leftTextPos -= ((Icons[icon_number].width  / 2) + 4);
          display.drawBitmap(Icons[icon_number].Icon, leftTextPos + u8g2Fonts.getUTF8Width(viewText.c_str()) + 8 + (( 24 - Icons[icon_number].width ) / 2) , icon_top, Icons[icon_number].width, Icons[icon_number].height, icon_colored ? GxEPD_RED : ePaper.ForegroundColor(), icon_colored ? GxEPD::bm_normal | GxEPD::bm_transparent | GxEPD::bm_invert : GxEPD::bm_default);
        }
        break;
      case AlignCenterIconLeft:
        leftTextPos = (display.width() / 2) - (fontWidth / 2);
        if (icon_number != 255) {
          leftTextPos += ((Icons[icon_number].width  / 2) + 4);
          display.drawBitmap(Icons[icon_number].Icon, leftTextPos - Icons[icon_number].width - 8 , icon_top, Icons[icon_number].width, Icons[icon_number].height, icon_colored ? GxEPD_RED : ePaper.ForegroundColor(), icon_colored ? GxEPD::bm_normal | GxEPD::bm_transparent | GxEPD::bm_invert : GxEPD::bm_default);
        }
        break;
      case AlignRight:
      default:
        leftTextPos = display.width() - 40 - fontWidth;
        if (icon_number != 255) display.drawBitmap(Icons[icon_number].Icon, display.width() - 32 + (( 24 - Icons[icon_number].width ) / 2) , icon_top, Icons[icon_number].width, Icons[icon_number].height, icon_colored ? GxEPD_RED : ePaper.ForegroundColor(), icon_colored ? GxEPD::bm_normal | GxEPD::bm_transparent | GxEPD::bm_invert : GxEPD::bm_default);
        break;
    }

    u8g2Fonts.setCursor(leftTextPos, y);


#ifdef USE_COLOR
    if (DisplayLines[i].TextColored == true) u8g2Fonts.setForegroundColor(GxEPD_RED);
#endif

    u8g2Fonts.print(viewText);

#ifdef USE_COLOR
    ePaper.setDisplayColors();
#endif
  }
}

void initDisplay() {
  display.fillScreen(ePaper.BackgroundColor());

  uint8_t serial[11];
  sdev.getDeviceSerial(serial);
  serial[10] = 0;

  #define TOSTRING(x) #x
  #define TOSTR(x) TOSTRING(x)

  const char * title        PROGMEM = "HB-Dis-EP-42BW";
  const char * asksinpp     PROGMEM = "AskSin++";
  const char * version      PROGMEM = "V " ASKSIN_PLUS_PLUS_VERSION_STR;
  const char * compiledMsg  PROGMEM = "compiled on";
  const char * compiledDate PROGMEM = __DATE__ " " __TIME__;
#ifdef USE_COLOR
  const char * pages        PROGMEM = "GxGDEW042Z15_PAGES: " TOSTR(GxGDEW042Z15_PAGES);
#else
  const char * pages        PROGMEM = "GxGDEW042T2_PAGES: " TOSTR(GxGDEW042T2_PAGES);
#endif
  const char * ser                  = (char*)serial;
  const char * nomaster1    PROGMEM = "- keine Zentrale -";
  const char * nomaster2    PROGMEM = "- angelernt -";

  u8g2Fonts.setFont(u8g2_font_helvB24_tf);
  u8g2Fonts.setCursor(centerPosition(title), 95);
#ifdef USE_COLOR
  u8g2Fonts.setForegroundColor(GxEPD_RED);
#endif
  u8g2Fonts.print(title);

  u8g2Fonts.setCursor(centerPosition(asksinpp), 170);
#ifdef USE_COLOR
    u8g2Fonts.setForegroundColor(ePaper.ForegroundColor());
#endif
  u8g2Fonts.print(asksinpp);

  u8g2Fonts.setCursor(centerPosition(version), 210);
  u8g2Fonts.print(version);

  u8g2Fonts.setFont(u8g2_font_helvB12_tf);
  u8g2Fonts.setCursor(centerPosition(compiledMsg), 235);
  u8g2Fonts.print(compiledMsg);
  u8g2Fonts.setCursor(centerPosition(compiledDate), 255);
  u8g2Fonts.print(compiledDate);
#ifdef USE_COLOR
    ePaper.setDisplayColors();
#endif

  u8g2Fonts.setFont(u8g2_font_helvR10_tf);
  u8g2Fonts.setCursor(centerPosition(pages), 275);
  u8g2Fonts.print(pages);

  u8g2Fonts.setFont(u8g2_font_helvB18_tf);
  u8g2Fonts.setCursor(centerPosition(ser), 320);
  u8g2Fonts.print(ser);

  if (sdev.getList0().masterid().valid() == false) {
    u8g2Fonts.setFont(u8g2_font_helvB18_tf);
    u8g2Fonts.setCursor(centerPosition(nomaster1), 360);u8g2Fonts.print(nomaster1);
    u8g2Fonts.setCursor(centerPosition(nomaster2), 386);u8g2Fonts.print(nomaster2);
  }

#ifdef USE_COLOR
  display.drawRect(50, 138, 200, 145, GxEPD_RED);
#else
  display.drawRect(50, 138, 200, 145, ePaper.ForegroundColor());
#endif
}

void emptyBatteryDisplay() {
  display.fillScreen(ePaper.BackgroundColor());
#ifdef USE_COLOR
  uint16_t fg = GxEPD_RED;
#else
  uint16_t fg = ePaper.ForegroundColor();
#endif
  display.fillRect(120, 80, 60, 40, fg);

  uint8_t batt_x = 80;
  uint8_t batt_y = 120;
  uint8_t batt_w = 140;
  uint8_t batt_h = 230;
  uint8_t line_w = 4;

  for (uint8_t i = 0 ; i < line_w; i++) {
    display.drawRect(batt_x + i, batt_y + i, batt_w - i*2, batt_h - i*2, fg);
    display.drawLine(batt_x + i, batt_y + batt_h - 1, batt_x + batt_w - line_w + i, batt_y + 1,fg);
  }
}

void outOfHouseDisplay() {
  display.fillScreen(ePaper.BackgroundColor());
#ifdef USE_COLOR
 uint16_t fg = GxEPD_RED;
#else
 uint16_t fg = ePaper.ForegroundColor();
#endif


 uint8_t home_x = 50;
 uint8_t home_y = 150;
 uint8_t home_w = 200;
 uint8_t home_h = 230;
 uint8_t line_w = 4;

 for (uint8_t i = 0 ; i < line_w; i++) {
   display.drawRect(home_x + i, home_y + i, home_w - i*2, home_h - i*2, fg);
   display.drawLine(home_x + i, home_y + i, home_y + i , home_x + i, fg);
   display.drawLine(home_y +i , home_x + i , home_x + home_w - i, home_y - i,  fg);
 }
}

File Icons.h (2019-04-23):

#ifndef _HB_ICONS_H_
#define _HB_ICONS_H_

#define ICON_COUNT    27
//https://javl.github.io/image2cpp/

// 'icon0', 23x24px
const unsigned char icon0 [] PROGMEM = {
  0xff, 0xff, 0xfe, 0xff, 0xe7, 0xf2, 0xff, 0xe7, 0xe6, 0xf7, 0xe7, 0xc6, 0xf3, 0xff, 0x8e, 0xf9,
  0xc7, 0x9e, 0xff, 0x00, 0x3e, 0xfe, 0x3c, 0x7e, 0xfc, 0x5c, 0x7e, 0x84, 0x98, 0x22, 0x84, 0x33,
  0x22, 0xfc, 0x23, 0x3e, 0xfc, 0x07, 0x3e, 0xfc, 0x8f, 0x3e, 0xfc, 0x1e, 0x7e, 0xfe, 0x3c, 0x7e,
  0xfe, 0x3c, 0xfe, 0xfc, 0x3d, 0xfe, 0xf8, 0x39, 0xfe, 0xf9, 0x01, 0xfe, 0xf3, 0x99, 0xfe, 0xe7,
  0x81, 0xfe, 0xcf, 0x83, 0xfe, 0xff, 0xff, 0xfe
};
// 'icon1', 23x24px
const unsigned char icon1 [] PROGMEM = {
  0xff, 0xff, 0xfe, 0xff, 0xe7, 0xfe, 0xff, 0xe7, 0xfe, 0xf7, 0xe7, 0xee, 0xf3, 0xff, 0xce, 0xf9,
  0xc7, 0xbe, 0xff, 0x00, 0xfe, 0xfe, 0x3c, 0x7e, 0xfc, 0x5e, 0x7e, 0x84, 0x9f, 0x22, 0x84, 0x3f,
  0x22, 0xfc, 0x3f, 0x3e, 0xfc, 0x3f, 0x3e, 0xfc, 0xff, 0x3e, 0xfc, 0x7e, 0x7e, 0xfe, 0x7c, 0x7e,
  0xff, 0x3c, 0xfe, 0xff, 0x3d, 0xfe, 0xff, 0x39, 0xfe, 0xff, 0x01, 0xfe, 0xff, 0x99, 0xfe, 0xff,
  0x81, 0xfe, 0xff, 0x83, 0xfe, 0xff, 0xff, 0xfe
};
// 'icon2', 18x24px
const unsigned char icon2 [] PROGMEM = {
  0xfe, 0x3f, 0xc0, 0xf8, 0x0f, 0xc0, 0xf0, 0x03, 0xc0, 0xf1, 0xe1, 0xc0, 0xe3, 0xf0, 0xc0, 0xe3,
  0xf8, 0xc0, 0xf7, 0xfc, 0x40, 0xff, 0xfc, 0x40, 0xff, 0xfc, 0xc0, 0xff, 0xf8, 0xc0, 0x80, 0x00,
  0x40, 0x00, 0x00, 0x00, 0x00, 0x00, 0x00, 0x00, 0x00, 0x00, 0x01, 0xe0, 0x00, 0x01, 0xe0, 0x00,
  0x01, 0xe0, 0x00, 0x00, 0xc0, 0x00, 0x00, 0xc0, 0x00, 0x00, 0xc0, 0x00, 0x00, 0x00, 0x00, 0x00,
  0x00, 0x00, 0x00, 0x00, 0x00, 0x80, 0x00, 0x40
};
// 'icon3', 19x24px
const unsigned char icon3 [] PROGMEM = {
  0xfe, 0x0f, 0xe0, 0xf0, 0x01, 0xe0, 0xe0, 0x00, 0xe0, 0xe1, 0xf0, 0xe0, 0xc3, 0xf8, 0x60, 0xc7,
  0xfc, 0x60, 0xc7, 0xfc, 0x60, 0xc7, 0xfc, 0x60, 0xc7, 0xfc, 0x60, 0xc0, 0x00, 0x60, 0x80, 0x00,
  0x20, 0x00, 0x00, 0x00, 0x00, 0x00, 0x00, 0x00, 0x40, 0x00, 0x00, 0xe0, 0x00, 0x01, 0xf0, 0x00,
  0x00, 0xe0, 0x00, 0x00, 0xe0, 0x00, 0x00, 0x40, 0x00, 0x00, 0x40, 0x00, 0x00, 0x00, 0x00, 0x00,
  0x00, 0x00, 0x00, 0x00, 0x00, 0x80, 0x00, 0x20
};
// 'icon4', 24x24px
const unsigned char icon4 [] PROGMEM = {
  0xff, 0xff, 0xff, 0x9f, 0xff, 0xf1, 0x8f, 0xff, 0xe1, 0x87, 0xff, 0xc1, 0xc3, 0xff, 0x83, 0xe1,
  0xff, 0x07, 0xf0, 0xff, 0x0f, 0xf8, 0x7e, 0x1f, 0xfc, 0x3c, 0x3f, 0xfe, 0x18, 0x7f, 0xff, 0x00,
  0xff, 0xff, 0x81, 0xff, 0xff, 0xc3, 0xff, 0xff, 0x81, 0xff, 0xff, 0x00, 0xff, 0xfe, 0x18, 0x7f,
  0xfc, 0x3c, 0x3f, 0xf8, 0x7e, 0x0f, 0xf0, 0xff, 0x07, 0xe1, 0xff, 0x83, 0xc3, 0xff, 0xc1, 0x87,
  0xff, 0xe1, 0x8f, 0xff, 0xf1, 0xff, 0xff, 0xff
};
// 'icon5', 21x24px
const unsigned char icon5 [] PROGMEM = {
  0xff, 0xff, 0xf8, 0xff, 0xff, 0xc8, 0xff, 0xff, 0x88, 0xff, 0xff, 0x88, 0xff, 0xff, 0x18, 0xff,
  0xff, 0x18, 0xff, 0xfe, 0x38, 0xff, 0xfe, 0x38, 0xff, 0xfc, 0x78, 0xff, 0xfc, 0x78, 0x9f, 0xf8,
  0xf8, 0x8f, 0xf0, 0xf8, 0x87, 0xf1, 0xf8, 0xc7, 0xe1, 0xf8, 0xc3, 0xe3, 0xf8, 0xe3, 0xc3, 0xf8,
  0xf1, 0xc7, 0xf8, 0xf0, 0xc7, 0xf8, 0xf8, 0x8f, 0xf8, 0xfc, 0x0f, 0xf8, 0xfc, 0x1f, 0xf8, 0xfe,
  0x1f, 0xf8, 0xfe, 0x3f, 0xf8, 0xff, 0xff, 0xf8
};
// 'icon6', 7x24px
const unsigned char icon6 [] PROGMEM = {
  0xc6, 0x82, 0x00, 0x82, 0x82, 0xfe, 0xfe, 0xc6, 0x82, 0x82, 0x82, 0x82, 0x82, 0x82, 0x82, 0x82,
  0x82, 0x82, 0x82, 0x82, 0x82, 0x82, 0x82, 0xfe
};
// 'icon7', 24x19px
const unsigned char icon7 [] PROGMEM = {
  0x80, 0x00, 0x01, 0x00, 0x00, 0x00, 0x07, 0xff, 0xe0, 0x23, 0xff, 0xc4, 0x31, 0xff, 0x8c, 0x38,
  0xff, 0x1c, 0x3e, 0x3c, 0x7c, 0x3f, 0x18, 0xfc, 0x3f, 0x81, 0xfc, 0x3f, 0xc3, 0xfc, 0x3f, 0xff,
  0xfc, 0x3f, 0xff, 0xfc, 0x3f, 0xff, 0xfc, 0x3f, 0xff, 0xfc, 0x3f, 0xff, 0xfc, 0x3f, 0xff, 0xfc,
  0x3f, 0xff, 0xfc, 0x00, 0x00, 0x00, 0x80, 0x00, 0x01
};
// 'icon8', 24x24px
const unsigned char icon8 [] PROGMEM = {
  0xff, 0xff, 0xff, 0xff, 0x79, 0xff, 0xfe, 0x00, 0xff, 0xfe, 0x00, 0x1f, 0xe0, 0x00, 0x0f, 0xe0,
  0x7c, 0x0f, 0xe1, 0xff, 0x0f, 0xe3, 0xff, 0x87, 0x87, 0xff, 0xc1, 0x07, 0xff, 0xc1, 0x0f, 0xff,
  0xe3, 0x8f, 0xff, 0xe3, 0xcf, 0xff, 0xe3, 0xcf, 0xff, 0xe1, 0x8f, 0xff, 0xe1, 0x87, 0xff, 0xc1,
  0x87, 0xff, 0xc7, 0xe3, 0xff, 0x87, 0xe1, 0xff, 0x07, 0xe0, 0x7c, 0x07, 0xf0, 0x00, 0x0f, 0xfe,
  0x00, 0x7f, 0xff, 0x08, 0xff, 0xff, 0x1f, 0xff
};
// 'icon9', 24x24px
const unsigned char icon9 [] PROGMEM = {
  0xff, 0xff, 0xff, 0xff, 0xc7, 0xff, 0xff, 0x81, 0xff, 0xff, 0x00, 0xff, 0xfe, 0x00, 0x7f, 0xf8,
  0x00, 0x3f, 0xf0, 0x00, 0x0f, 0xe0, 0x00, 0x07, 0x80, 0x00, 0x03, 0x80, 0xff, 0x01, 0xc1, 0xff,
  0x83, 0xc1, 0x81, 0x83, 0xc1, 0x01, 0xc3, 0xc7, 0x00, 0xe3, 0xcf, 0xff, 0xf3, 0xc7, 0xff, 0xe3,
  0xc6, 0x7e, 0xe3, 0xc6, 0x7e, 0x63, 0xc7, 0xff, 0xe3, 0xc7, 0xc5, 0xe3, 0xc7, 0x00, 0xe3, 0xc0,
  0x00, 0x03, 0xff, 0xff, 0xff, 0xff, 0xff, 0xff
};
// 'icon10', 24x24px
const unsigned char icon10 [] PROGMEM = {
  0xff, 0xff, 0xff, 0xff, 0xff, 0xff, 0xff, 0xff, 0xff, 0xc0, 0x00, 0x01, 0xc0, 0x00, 0x03, 0xff,
  0xff, 0xff, 0xc0, 0x00, 0x01, 0xc0, 0x00, 0x03, 0xff, 0xff, 0xff, 0xc0, 0x00, 0x01, 0xc0, 0x00,
  0x03, 0xfb, 0xff, 0xcf, 0xfb, 0xff, 0xcb, 0xfb, 0xff, 0xcf, 0xfb, 0xff, 0xcf, 0xfb, 0xff, 0xcb,
  0xfb, 0xff, 0xcf, 0xfb, 0xff, 0xcf, 0xfb, 0xff, 0xcb, 0xf9, 0xff, 0x9f, 0xf8, 0x00, 0x1f, 0xff,
  0xff, 0xff, 0xff, 0xff, 0xff, 0xff, 0xff, 0xff
};
// 'icon11', 24x24px
const unsigned char icon11 [] PROGMEM = {
  0xff, 0xff, 0xff, 0xff, 0xff, 0xff, 0xff, 0xff, 0xff, 0xc0, 0x00, 0x01, 0xc0, 0x00, 0x03, 0xff,
  0xff, 0xff, 0xc0, 0x00, 0x01, 0xc0, 0x00, 0x03, 0xff, 0xff, 0xff, 0xc0, 0x00, 0x01, 0xc0, 0x00,
  0x03, 0xfb, 0xff, 0xcf, 0xfb, 0xff, 0xcb, 0xfb, 0xe7, 0xcf, 0xfb, 0xc3, 0xcf, 0xfb, 0x81, 0xcb,
  0xfb, 0x81, 0xcf, 0xfb, 0xff, 0xcf, 0xfb, 0xff, 0xcb, 0xf9, 0xff, 0x9f, 0xf8, 0x00, 0x1f, 0xff,
  0xff, 0xff, 0xff, 0xff, 0xff, 0xff, 0xff, 0xff
};
// 'icon12', 24x24px
const unsigned char icon12 [] PROGMEM = {
  0xff, 0xff, 0xff, 0xff, 0xff, 0xff, 0xff, 0xff, 0xff, 0xc0, 0x00, 0x01, 0xc0, 0x00, 0x03, 0xff,
  0xff, 0xff, 0xc0, 0x00, 0x01, 0xc0, 0x00, 0x03, 0xff, 0xff, 0xff, 0xc0, 0x00, 0x01, 0xc0, 0x00,
  0x03, 0xfb, 0xff, 0xcf, 0xfb, 0xff, 0xcb, 0xfb, 0xff, 0xcf, 0xfb, 0x81, 0xcf, 0xfb, 0xc3, 0xcb,
  0xfb, 0xe7, 0xcf, 0xfb, 0xff, 0xcf, 0xfb, 0xff, 0xcb, 0xf9, 0xff, 0x9f, 0xf8, 0x00, 0x1f, 0xff,
  0xff, 0xff, 0xff, 0xff, 0xff, 0xff, 0xff, 0xff
};
// 'icon13', 24x24px
const unsigned char icon13 [] PROGMEM = {
  0xff, 0xff, 0xff, 0xff, 0xe7, 0xff, 0xff, 0xc3, 0xff, 0xff, 0x81, 0xff, 0xff, 0x00, 0xff, 0xfe,
  0x00, 0x7f, 0xfc, 0x00, 0x3f, 0xf8, 0x00, 0x1f, 0xf0, 0x00, 0x0f, 0xff, 0x81, 0xff, 0xff, 0x81,
  0xff, 0xff, 0x81, 0xff, 0xff, 0x81, 0xff, 0xff, 0x81, 0xff, 0xff, 0x81, 0xff, 0xff, 0x81, 0xff,
  0xff, 0x81, 0xff, 0xff, 0x81, 0xff, 0xff, 0x81, 0xff, 0xff, 0x81, 0xff, 0xff, 0x81, 0xff, 0xff,
  0x81, 0xff, 0xff, 0xff, 0xff, 0xff, 0xff, 0xff
};
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

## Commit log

2018-12-09 Schematic V0.1
    [HB-Dis-EP-42BW.sch]
2018-12-15 lots of changes
    - TH buttons
    - footprint of ePaper
    - footprint of adapter board
    [HB-Dis-EP-42BW.kicad_pcb, HB-Dis-EP-42BW.sch]
2018-12-15 initial PCB placement
    [HB-Dis-EP-42BW.kicad_pcb, HB-Dis-EP-42BW.sch]
2018-12-16 routing...
    - moved decoupling caps to bottom side
    - routed most of it
    - looks like the button pins shall be rearranged for better routing
    [HB-Dis-EP-42BW.kicad_pcb]
2018-12-16 first board layout done, buttons swapped
    buttons are connected differently to simplify routing
    [HB-Dis-EP-42BW.kicad_pcb, HB-Dis-EP-42BW.sch]
2018-12-16 added opt. 8 MHz resonator
    [HB-Dis-EP-42BW.kicad_pcb, HB-Dis-EP-42BW.sch]
2018-12-20 replace bare ePaper by module
    [HB-Dis-EP-42BW.kicad_pcb, HB-Dis-EP-42BW.sch]
2019-01-05 do not replace chars in source array
    [HB-Dis-EP-42BW.ino]
2019-01-05 switched to MightyCore Standard Layout
2019-01-05 - added a LED to show that the epaper is workin - added define USE_CC1101_ALT_FREQ_86835 for non freq stable cc1101 - some smaller fixes
    [HB-Dis-EP-42BW.ino]
2019-01-05 added front stl
    [ePaper-Front.stl]
2019-01-13 several improvement on PCB
    - 4x GPIO for future use
    - battery measurement under switchable load
    - caps @ CC1101 and @ ePaper changed to 10 uF
    - extra solder points on the way to the ePaper connector
    (option to cut the upper 5 mm to fit the size of the bare ePaper)
    - remove copper layers in top left, to place antenna there
    [HB-Dis-EP-42BW.kicad_pcb, HB-Dis-EP-42BW.sch]
2019-01-17 further improvements to PCB
    - change caps @ CC1101 and @ ePaper to 1 uF
    - shrink GPIOs to 3
    - add I²C connecter for future use
    - move config button to desired place and add hole for optional head-over-heels mounting
    - add 6-pin JTAG header on backside
    [HB-Dis-EP-42BW.kicad_pcb, HB-Dis-EP-42BW.sch]
2019-01-20 even more improvements on PCB
    - slimmer pads on TQFP44 for easier soldering
    - CC1101 power pads changed to "oval" so that the net is connected horizontal/vertical and not diagonal
    - moved vias out of SMD pads
    [HB-Dis-EP-42BW.kicad_pcb, HB-Dis-EP-42BW.sch]
2019-01-20 replace VCC layer by net
    as suggested by TomMajor
    [HB-Dis-EP-42BW.kicad_pcb]
2019-01-29 small PCB improvments
    - enlarge VCC where connected to pads
    [HB-Dis-EP-42BW.kicad_pcb]
2019-02-01 last PCB improvements for V1.0
    - put correct mounting holes
    [HB-Dis-EP-42BW.kicad_pcb]
2019-02-23 change pin definition to match the PCB
    previous pin definition matched Jérôme's flywire setup
2019-02-28 updated BOM and ordering information
2019-02-28 more details about the assembly
2019-03-01 update resistor values for BI and LED
    [HB-Dis-EP-42BW.sch]
2019-03-03 minor change: replaced 'drawExampleBitmap' with 'drawBitmap'
    [HB-Dis-EP-42BW.ino]
2019-03-10 PCB V1.1
    - fix spacing and placement of buttons (8.5 mm instead of 9.0 mm)
    - add hole for CC1101 antenna
    - move battery connector a bit
    [HB-Dis-EP-42BW.kicad_pcb]
2019-03-10 PCB V1.1 3D pics
2019-03-15 Update HB-Dis-EP-42BW.kicad_pcb
    - move config button to bottom of pcb
    - fix some 3D symbols
    [HB-Dis-EP-42BW.kicad_pcb]
2019-03-26 - allow fixtext in dynamic texts - clear line with 0xfe
    [HB-Dis-EP-42BW.ino]
2019-03-27 check range for valid fix text number
    [HB-Dis-EP-42BW.ino]
2019-04-16 use separate register for display inverting and ledmode add lowbat value in list0
    [HB-Dis-EP-42BW.ino]
2019-04-21 introduce ePaperType class use RemoteChannel for buttons
2019-04-23 add battery icon
2019-04-23 implemented new device model for use with mains (no burst needed)
2019-05-03 moved ePaper Working LED into ePaperType class
2019-05-05 use dedicated channels for remote buttons and ActionCommandMsg
2019-07-02 send short/long key press on startup to trigger ccu
    [HB-Dis-EP-42BW.ino]
2019-07-02 reset button state to none
2019-07-05 set critical bat via webui show battery empty symbol on display
2021-01-13 Update HB-Dis-EP-42BW.ino
    real fix for v5.0.0
    [HB-Dis-EP-42BW.ino]

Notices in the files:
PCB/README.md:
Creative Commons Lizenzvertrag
